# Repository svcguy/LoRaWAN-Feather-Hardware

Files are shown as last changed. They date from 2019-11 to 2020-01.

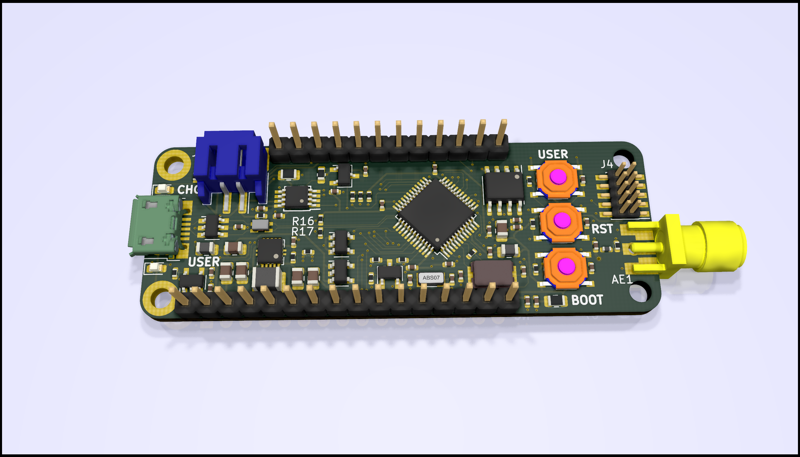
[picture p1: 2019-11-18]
doc/loRaWan1262_jlc.png

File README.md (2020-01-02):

# LoRaWAN Feather
## Overview
An Adafruit Feather compatiable board that is LoRaWAN compatible.  Designed to work with the Semtech LoRaWAN reference implementation.  Based on the STM32L073 micro and the Dorji DRF1262T radio module (which is based on the SX1262).  The board has the following hardware features:
* LiPo battery connector and charging as warranted by the Feather spec  
* LiPo fuel gauging as expected by the LoRaWAN reference implementation  
* Implements native USB  
* Connections for I2C, SPI, UART, GPIO, Analog and DAC.  
* An efficent DC-DC buck/boost switch mode converter.  
* Includes an ARM Cortex 10pin SWD debug connector  
* Antenna footprint supports edge mount SMA, u.FL and pigtail connections
* Footprint for U8 can support a hard secure element (ATECC608 or compatible) or an I2C FRAM allowing the user to experiment with hardware encryption or be LoRaWAN 1.1 compliant
* Includes one USER button as well as RESET and BOOT buttons  
* Includes one USER LED and a CHARGE LED.

## Changelog
### REV A0
Inital release
### REV B0
* Fix STC3100 grounding
* Make R16,R17 DNP by default
* Bump Bot Silk to REVB0
### REV C0
* Make U8 footprint capable of crypto and fram device
* Minor updates to schematic
* Minor updates to doc prints
* Update bot silk to REV C0

## Open Source
All schematics, pcb files, gerbers, BOM, CPL are available in this repo.  Part numbers for LCSC and Digikey are included

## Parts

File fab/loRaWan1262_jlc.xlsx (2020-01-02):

Comment | Designator | Footprint | Digikey | LCSC
Antenna_Shield | AE1 | Custom_KICAD:RF_ANT | CON-SMA-EDGE-S-ND | C129604
10uF | C10,C11,C30 | jlcpcb_smt:C_0805_2012Metric | 490-14381-1-ND | C15850
DNP | C12 | jlcpcb_smt:R_0402_1005Metric | DNP | DNP
DNP | C14 | jlcpcb_smt:C_0402_1005Metric | DNP | DNP
30pF | C24,C26 | jlcpcb_smt:C_0402_1005Metric | 311-1666-1-ND | C1570
15pF | C27,C29 | jlcpcb_smt:C_0402_1005Metric | 311-1017-1-ND | C1548
220nF | C3 | jlcpcb_smt:C_0402_1005Metric | 311-1035-1-ND | C16772
0.1uF | C4,C9,C15,C17,C18,C19,C20,C28,C25,C21,C23,C32 | jlcpcb_smt:C_0402_1005Metric | 490-14603-1-ND | C1525
1uF | C5,C6,C13,C16,C22,C1,C2,C33 | jlcpcb_smt:C_0402_1005Metric | 311-1439-1-ND | C52923
4.7uF | C7,C8,C31 | jlcpcb_smt:C_0805_2012Metric | 490-14466-1-ND | C1779
CHG | D1 | jlcpcb_smt:LED_0603_1608Metric | 160-1448-1-ND | C72038
USER | D2 | jlcpcb_smt:LED_0603_1608Metric | 160-1447-1-ND | C72043
MountingHole | H1,H2 | MountingHole:MountingHole_2.7mm_M2.5 | DNP | DNP
MountingHole_Pad | H3,H4 | MountingHole:MountingHole_2.7mm_M2.5_Pad | DNP | DNP
BAT | J1 | Connector_JST:JST_PH_S2B-PH-SM4-TB_1x02-1MP_P2.00mm_Horizontal | 455-1749-1-ND
Feather_BOT | J2 | Connector_PinHeader_2.54mm:PinHeader_1x16_P2.54mm_Vertical | DNP | DNP
Feather_TOP | J3 | Connector_PinHeader_2.54mm:PinHeader_1x12_P2.54mm_Vertical | DNP | DNP
SWD | J4 | Connector_PinHeader_1.27mm:PinHeader_2x05_P1.27mm_Vertical_SMD | SAM8796-ND | DNP
USB_B_Micro | J5 | Connector_USB:USB_Micro-B_Amphenol_10103594-0001LF_Horizontal | 609-4050-1-ND | C428495
2.2uH | L1 | jlcpcb_smt:L_1210_3225Metric | 490-2501-1-ND | C86074
FERRITE | L2 | jlcpcb_smt:R_0805_2012Metric | 587-1932-1-ND | C1015
0 | L3 | jlcpcb_smt:L_0402_1005Metric | 311-0.0JRCT-ND | C17168
FERRITE | L4,L5 | jlcpcb_smt:L_0805_2012Metric | 587-1932-1-ND | C1015
COMMON_MODE | L6 | jlcpcb_smt:COMMON_MODE_FILTER_0805 | 490-5137-1-ND | C86163
MMBT3904 | Q1 | jlcpcb_smt:TSOT-23 | MMBT3904-FDICT-ND | C20526
2k | R1 | jlcpcb_smt:R_0402_1005Metric | 311-2KLRCT-ND | C4109
330 | R10,R15,R2 | jlcpcb_smt:R_0402_1005Metric | 311-330LRCT-ND | C25104
100 | R11 | jlcpcb_smt:R_0402_1005Metric | 311-100LRTR-ND | C25076
0 | R12 | jlcpcb_smt:R_0402_1005Metric | 311-0.0JRCT-ND | C17168
1.5k | R16,R17 | jlcpcb_smt:R_0402_1005Metric | DNP | DNP
4.7k | R18,R19 | jlcpcb_smt:R_0402_1005Metric | 311-4.7KJRCT-ND | C25900
0.03 | R3 | jlcpcb_smt:R_0805_2012Metric | P124412CT-ND | C247605
200k | R5 | jlcpcb_smt:R_0603_1608Metric | A119933CT-ND | C61953
1k | R7,R4 | jlcpcb_smt:R_0402_1005Metric | 311-1.00KLRCT-ND | C11702
10k | R9,R8,R13,R14,R6 | jlcpcb_smt:R_0402_1005Metric | 311-10.0KLRTR-ND | C25744
USER | SW1 | jlcpcb_smt:TS_1187A | EG2531CT-ND | C318884
RESET | SW2 | jlcpcb_smt:TS_1187A | EG2531CT-ND | C318884
BOOT | SW3 | jlcpcb_smt:TS_1187A | EG2531CT-ND | C318884
MCP73831-2-OT | U1 | jlcpcb_smt:TSOT-23-5 | MCP73831T-2ATI/OTCT-ND | C424093
USBLC6-2SC6 | U10 | jlcpcb_smt:TSOT-23-6 | 497-5235-1-ND | C7519
STC3100 | U2 | jlcpcb_smt:MSOP-8_3x3mm_P0.65mm | 497-10526-1-ND
XC6206 | U3 | jlcpcb_smt:TSOT-23 | MCP1700T3302ETTCT-ND | C5446
MAX40200AUK | U5,U4 | Package_TO_SOT_SMD:SOT-23-5 | MAX40200AUK+TCT-ND
TPS63001 | U6 | jlcpcb_smt:Texas_S-PVSON-N10_ThermalVias | 296-19643-1-ND | C28060
DRF1262x | U7 | Custom_KICAD:DRF1262x | DNP | DNP
ATECC608A-SSHDA | U8 | jlcpcb_smt:SOIC-8_3.9x4.9mm_P1.27mm | ATECC608A-SSHCZ-TCT-ND | C376619
FM24CL04B | U8 | jlcpcb_smt:SOIC-8_3.9x4.9mm_P1.27mm | 428-3741-1-ND | C66016
STM32L073CZTx | U9 | jlcpcb_smt:LQFP-48_7x7mm_P0.5mm | 497-17506-ND | DNP
8MHz | Y1 | jlcpcb_smt:Crystal_SMD_Abracon_ABM3-2Pin_5.0x3.2mm | 535-10630-1-ND | C115962
32.768kHz | Y2 | jlcpcb_smt:Crystal_SMD_3215-2Pin_3.2x1.5mm | 535-9542-1-ND | C32346

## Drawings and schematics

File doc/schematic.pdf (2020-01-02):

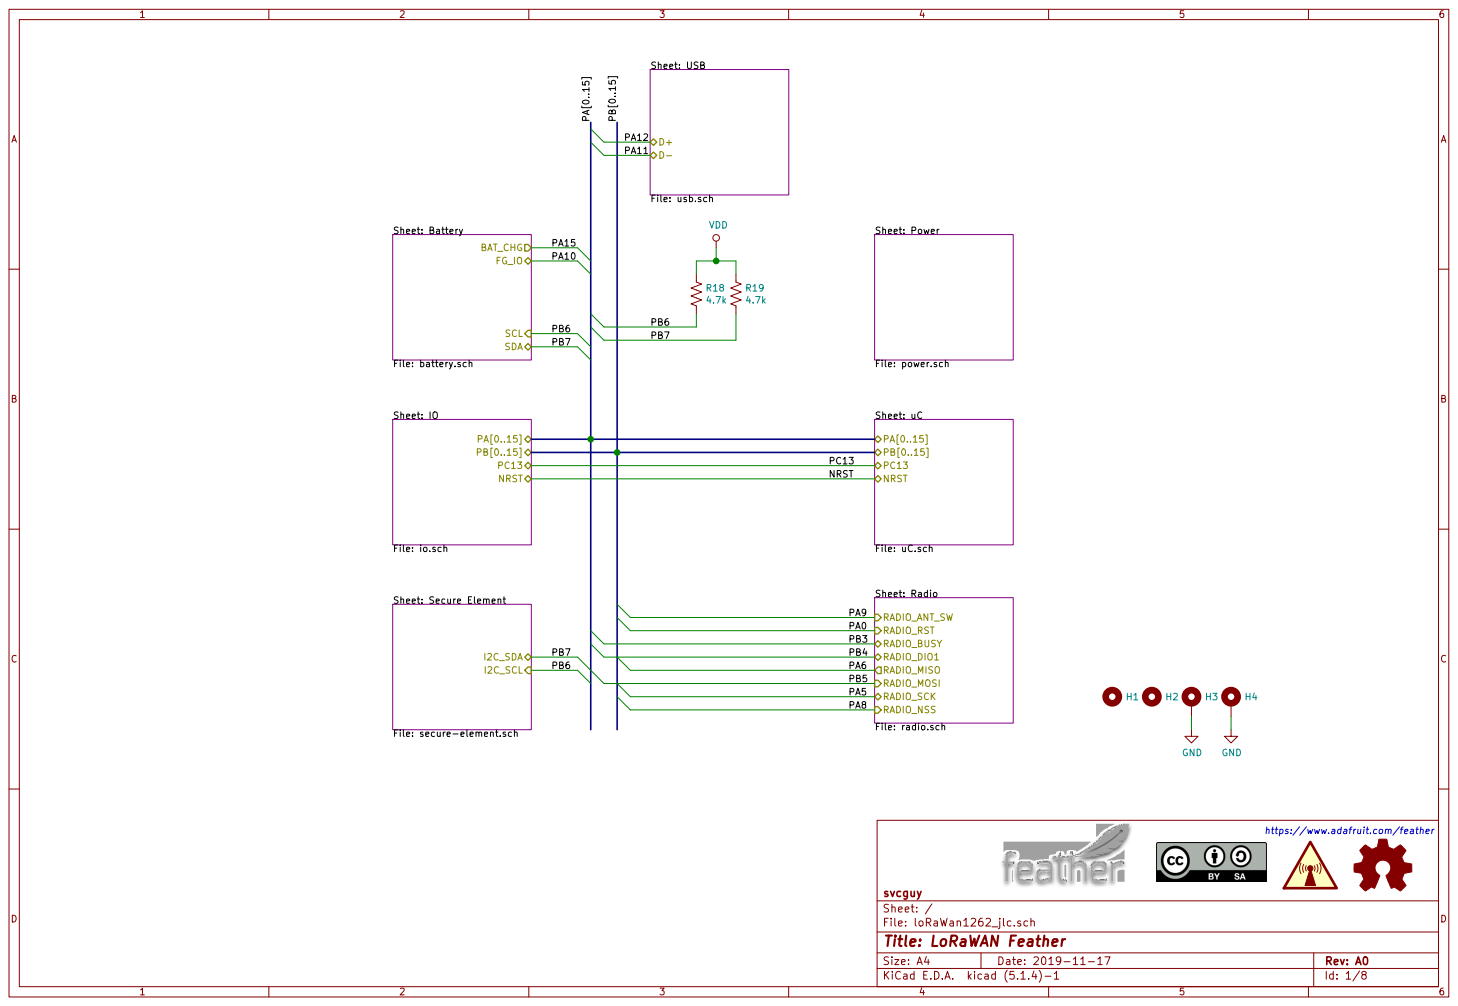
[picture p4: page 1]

PB[0..15] NRST Sheet: USB

File: usb.sch D+D- Sheet: IO

PB[0..15] NRST PC13 Sheet: Battery

4.7k VDD
Sheet: Power File: power.sch Sheet: Radio File: radio.sch RADIO_ANT_SW

File: uC.sch PC13 PA[0..15]

RADIO_RST RADIO_BUSY RADIO_DIO1 Sheet: Secure Element File: secure-element.sch

https://www.adafruit.com/feather

File: loRaWan1262_jlc.sch Sheet: / svcguy

Id: 1/8 Title: LoRaWAN Feather

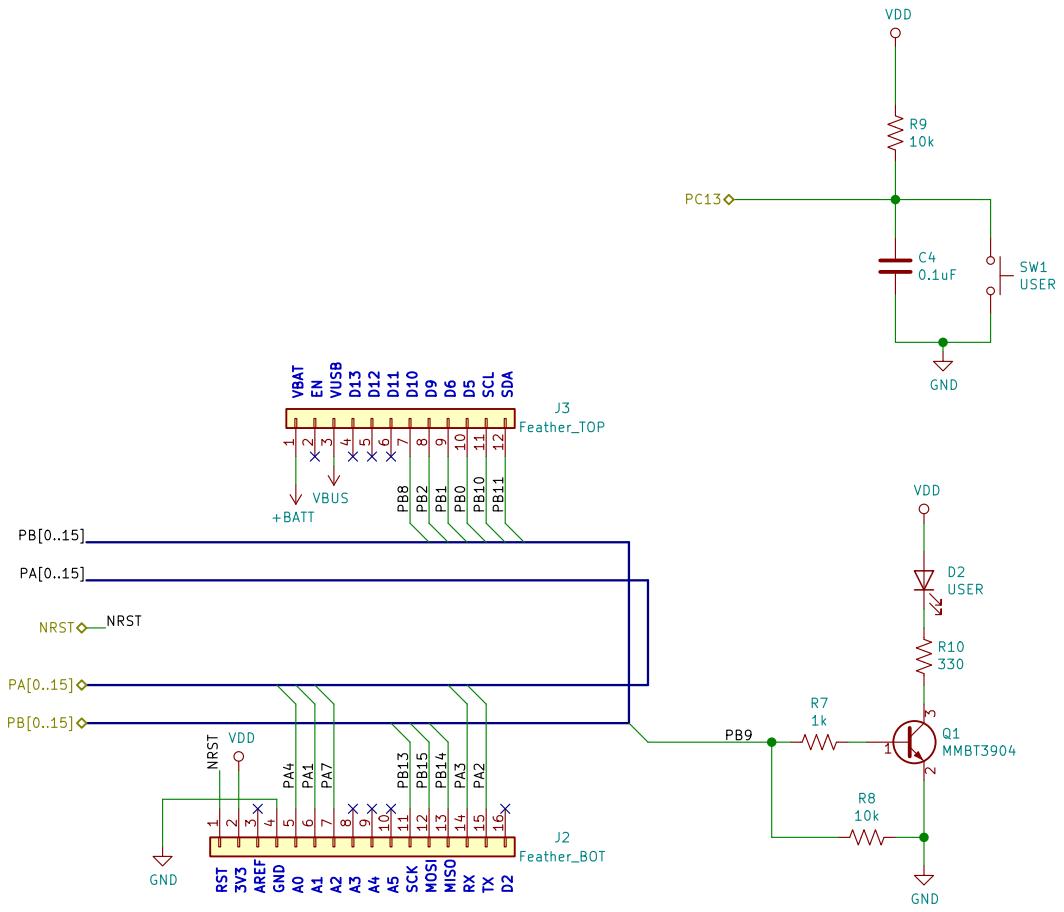
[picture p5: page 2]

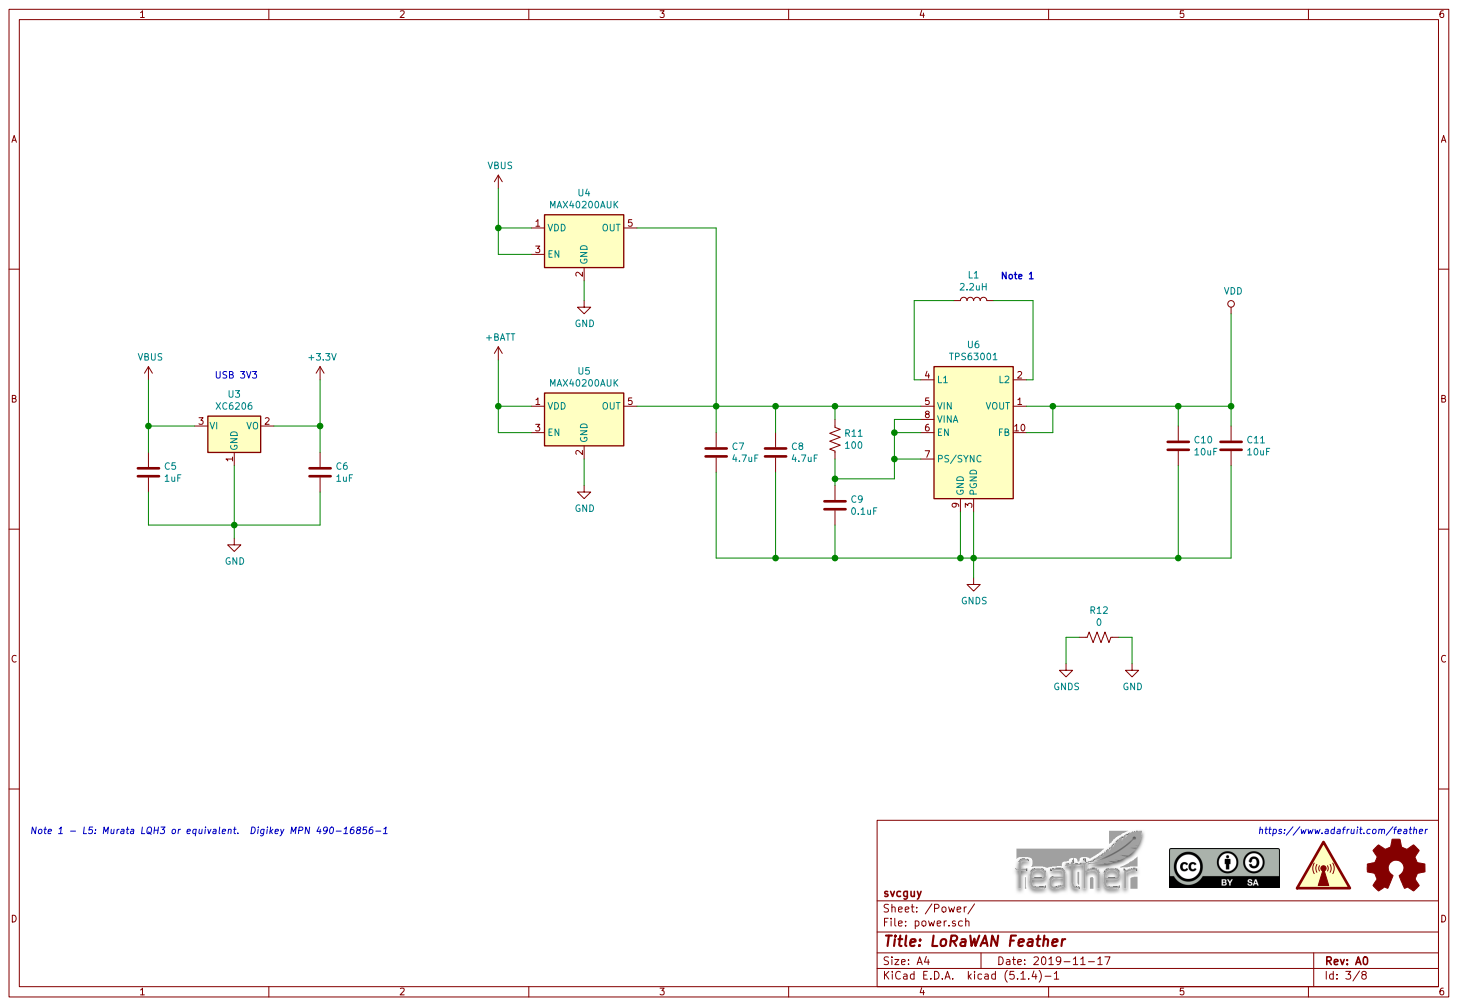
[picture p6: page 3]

2 EN 3 OUT 5 U4 MAX40200AUK GND GND GNDS GNDS GND

Id: 3/8 Title: LoRaWAN Feather

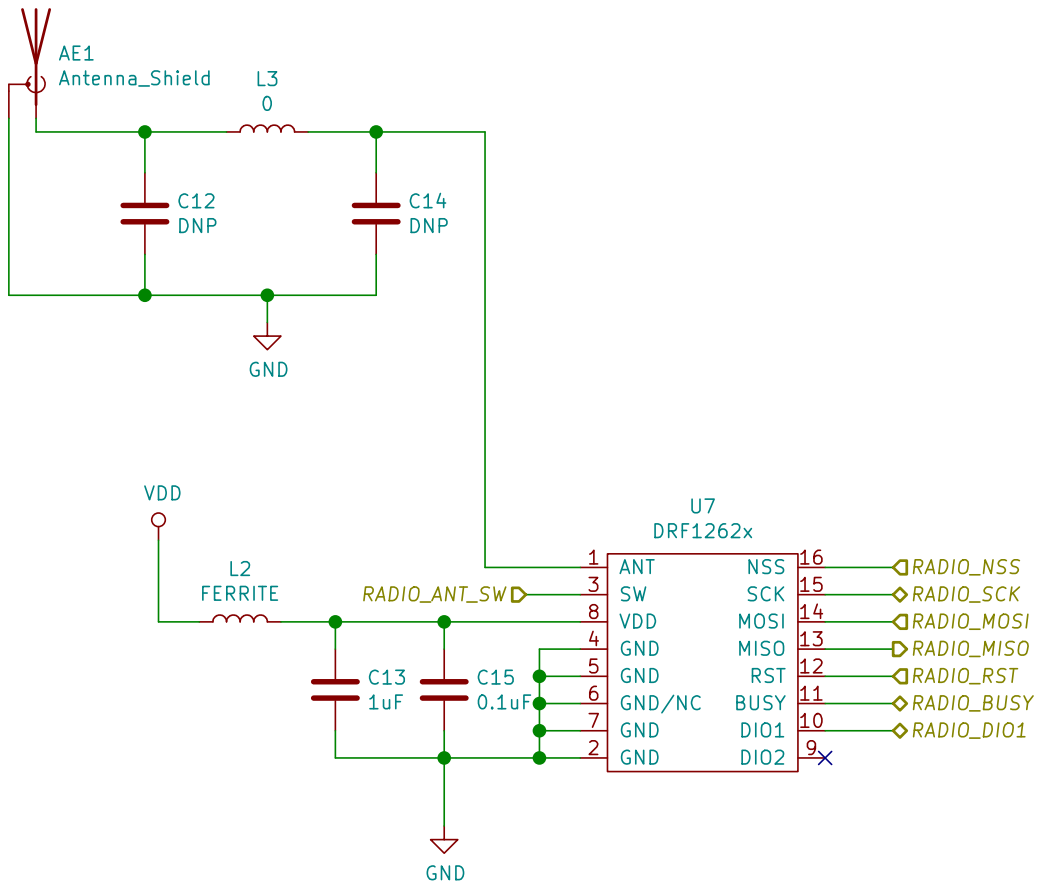
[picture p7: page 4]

https://www.adafruit.com/feather

Id: 4/8 Title: LoRaWAN Feather File: radio.sch Sheet: /Radio/ svcguy

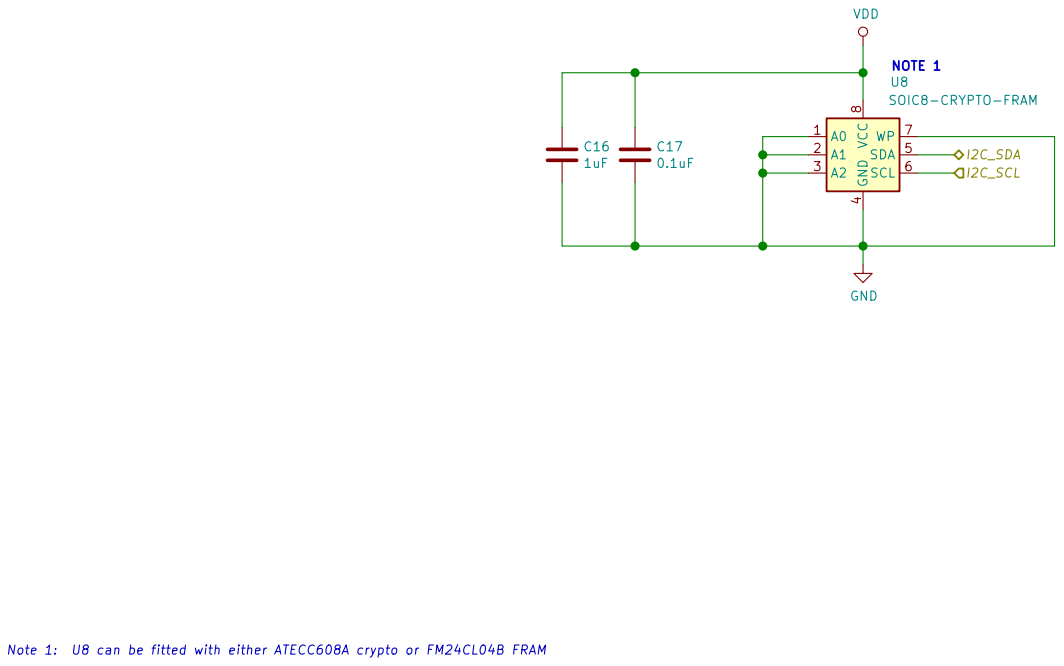
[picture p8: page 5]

https://www.adafruit.com/feather NOTE 1 Note 1: U8 can be fitted with either ATECC608A crypto or FM24CL04B FRAM

4 SDA 5 SCL 6 WP 7 VCC

Id: 5/8 Title: LoRaWAN Feather File: secure-element.sch Sheet: /Secure Element/ svcguy C16

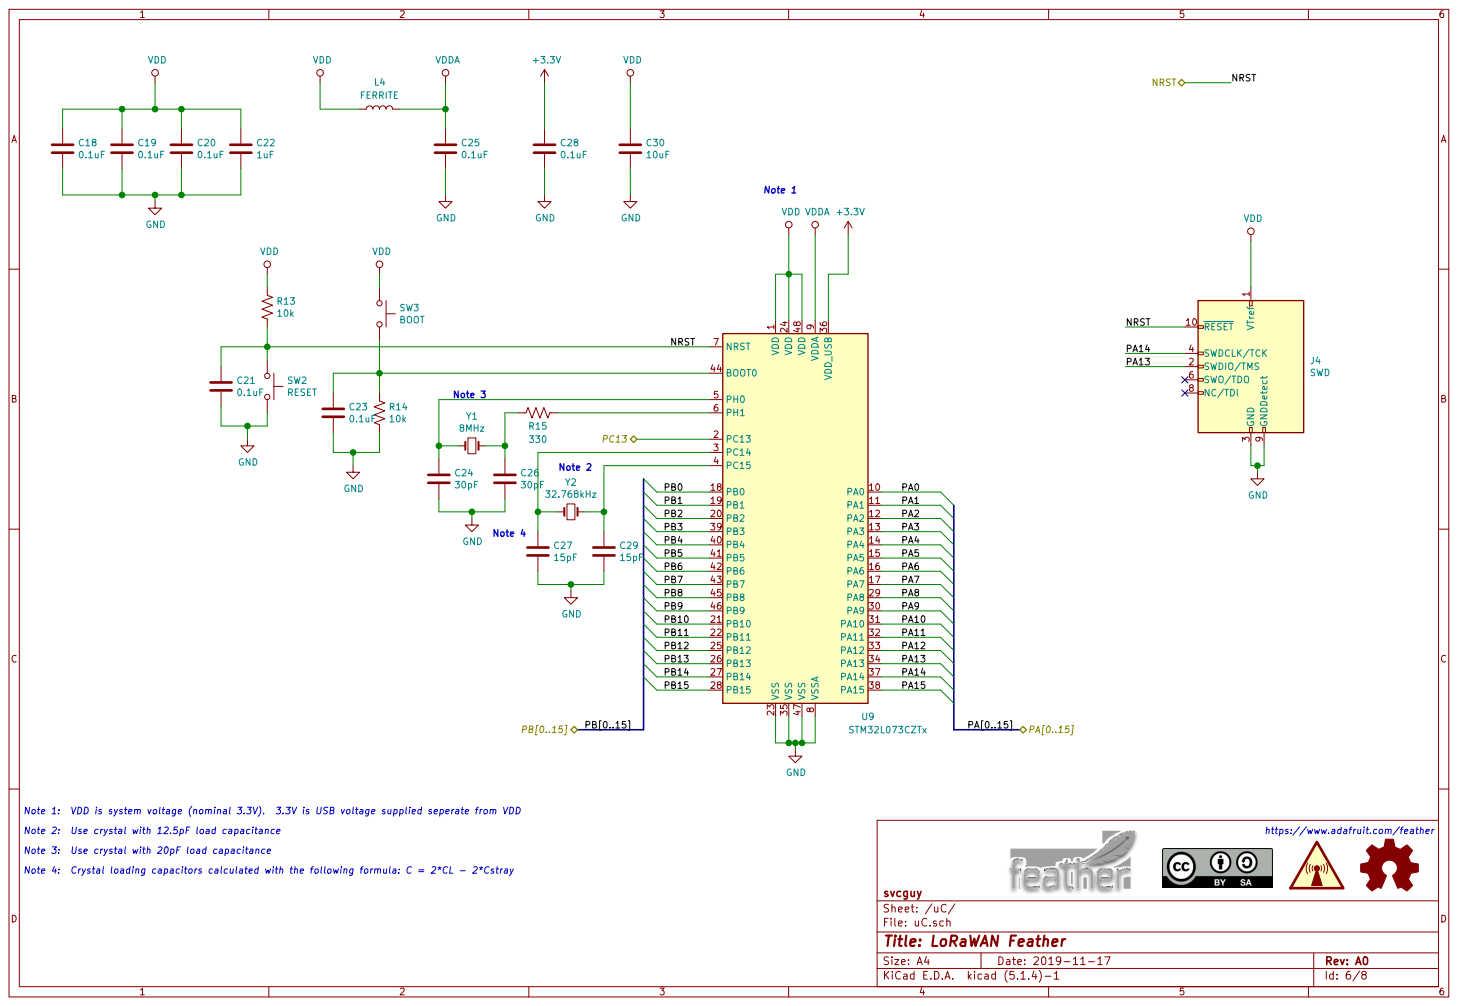
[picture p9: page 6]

9 VDD_USB 36 VSS 23 VSS 35 VSS 47 VSSA

3 SWDCLK/TCK 4 SWO/TDO 6 NC/TDI 8 GNDDetect 9

Note 1: VDD is system voltage (nominal 3.3V). 3.3V is USB voltage supplied seperate from VDD

https://www.adafruit.com/feather

Note 4: Crystal loading capacitors calculated with the following formula: C = 2*CL - 2*Cstray

Id: 6/8 Title: LoRaWAN Feather File: uC.sch Sheet: /uC/ svcguy

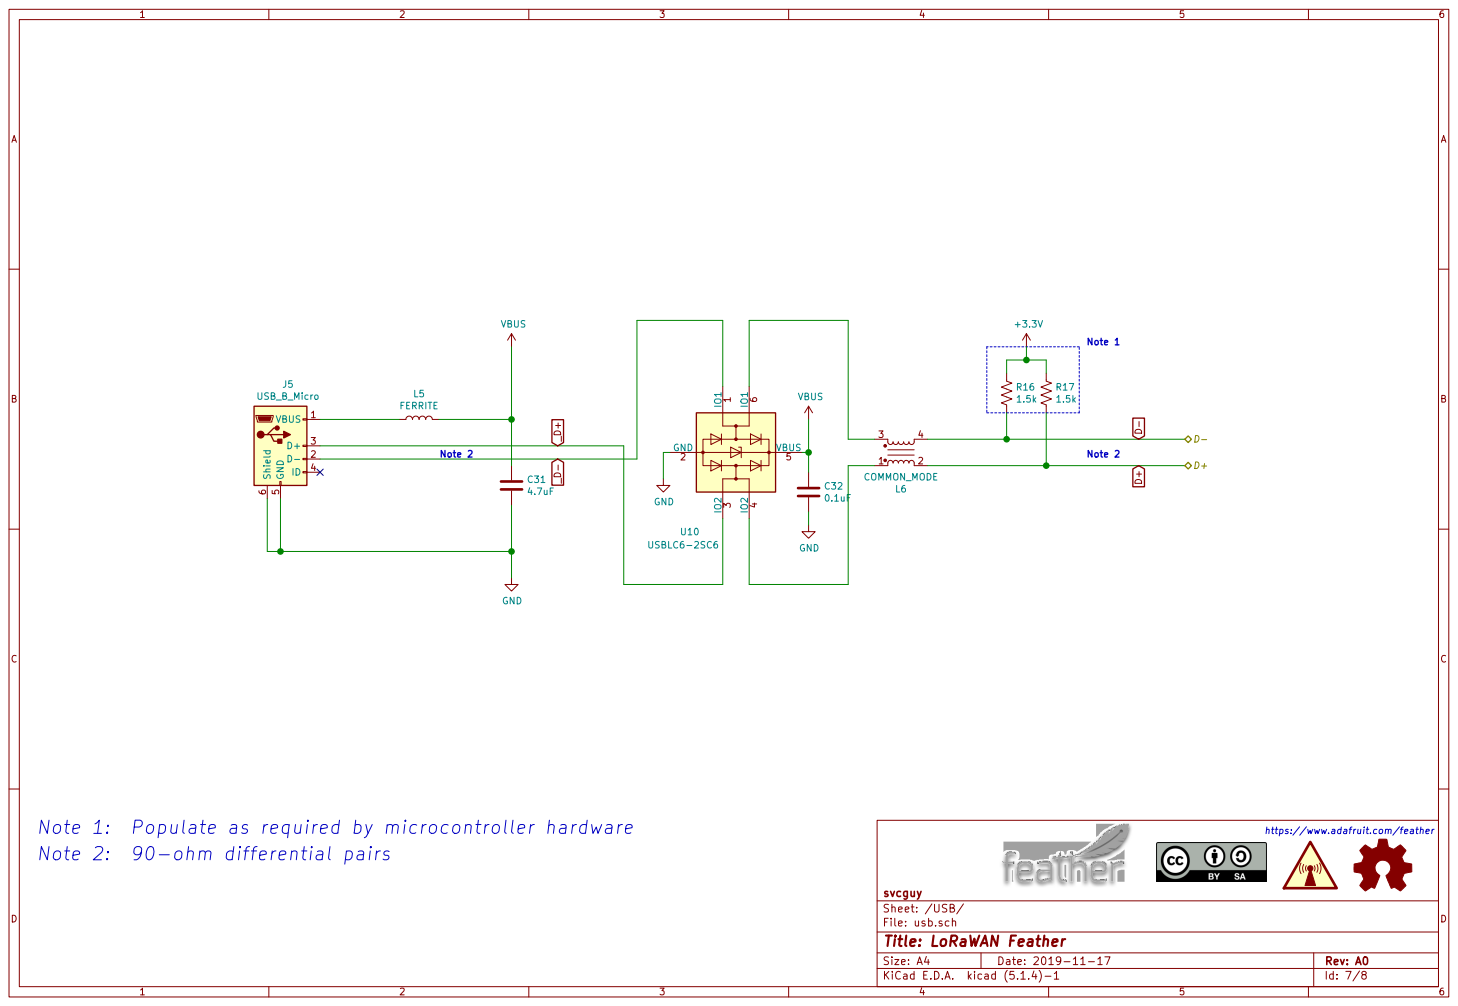
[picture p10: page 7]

https://www.adafruit.com/feather

Note 2: 90-ohm differential pairs

Id: 7/8 Title: LoRaWAN Feather File: usb.sch Sheet: /USB/ svcguy

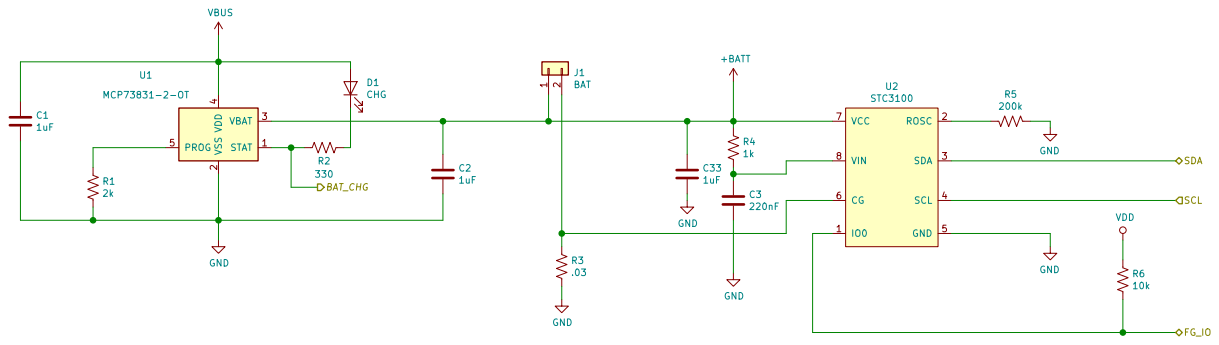
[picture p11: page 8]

4 PROG 5 U1 MCP73831-2-OT VBUS D1 CHG

https://www.adafruit.com/feather

Sheet: /Battery/
File: battery.sch
Id: 8/8 Title: LoRaWAN Feather

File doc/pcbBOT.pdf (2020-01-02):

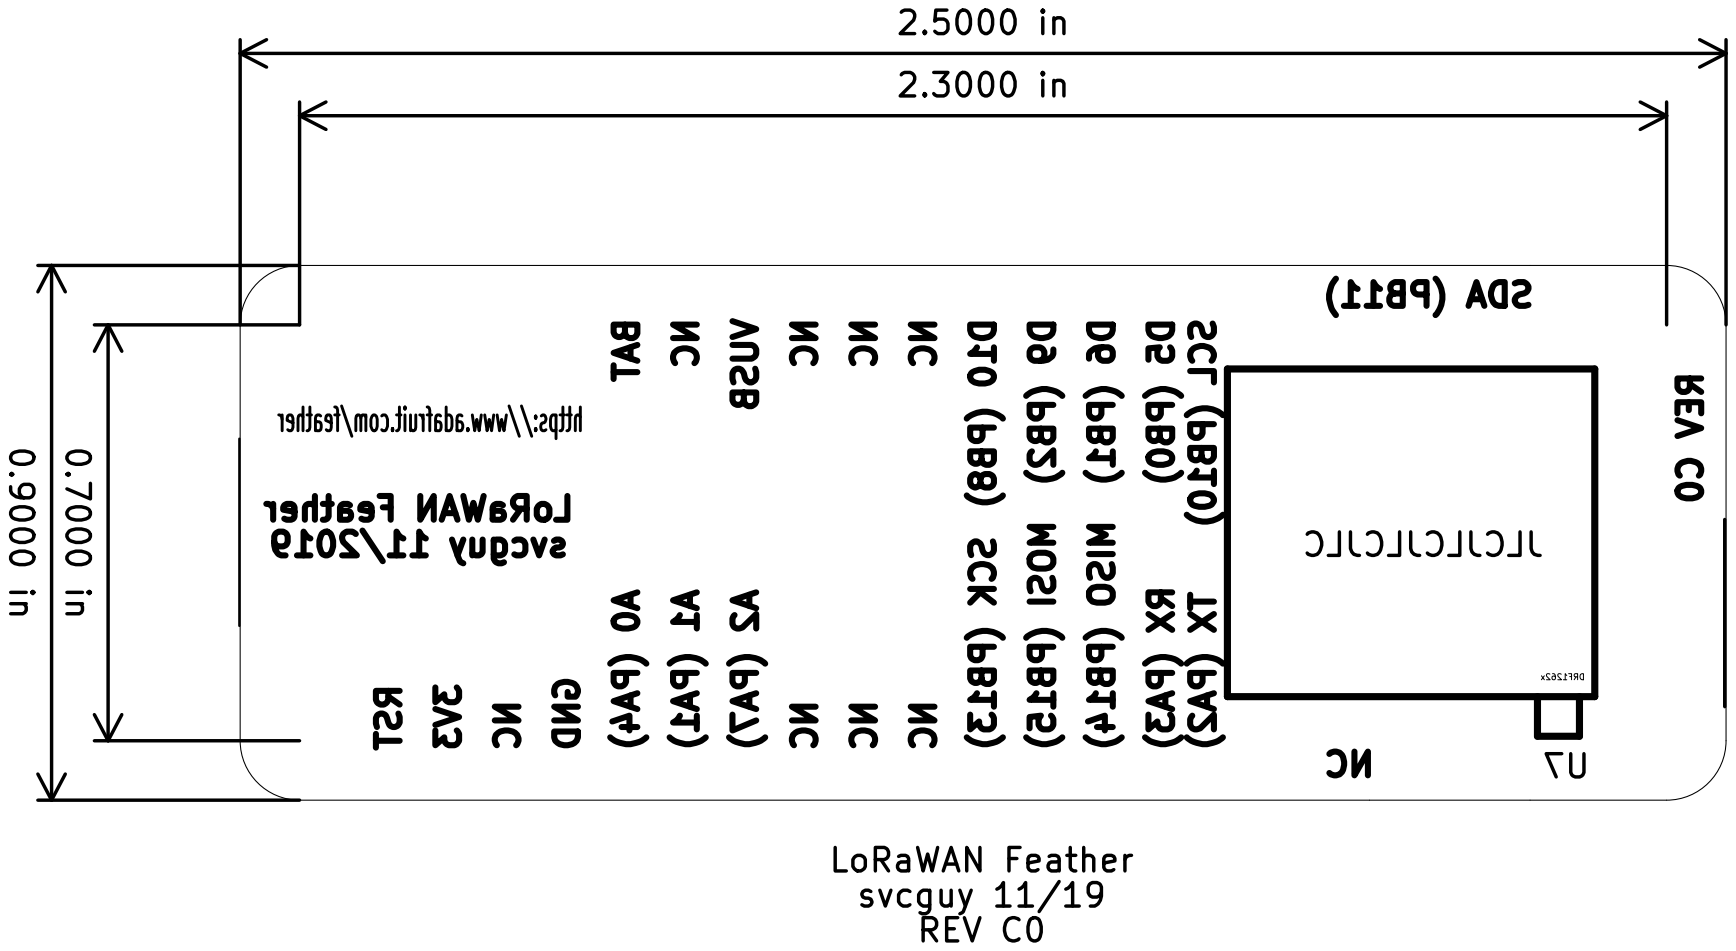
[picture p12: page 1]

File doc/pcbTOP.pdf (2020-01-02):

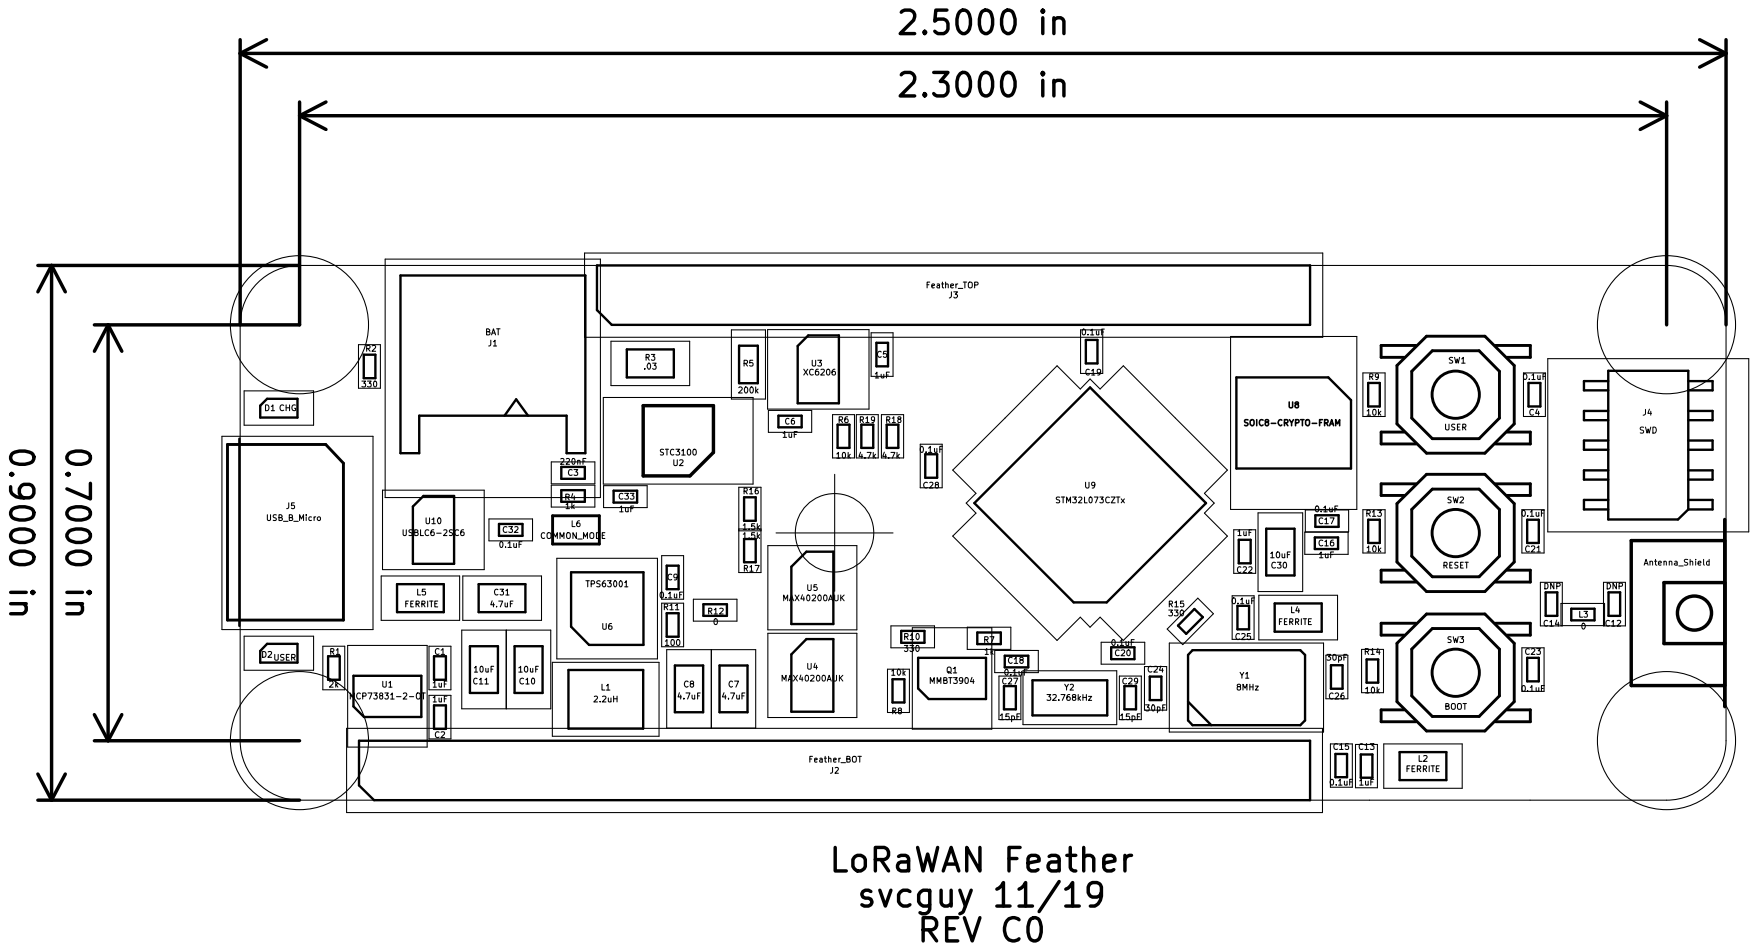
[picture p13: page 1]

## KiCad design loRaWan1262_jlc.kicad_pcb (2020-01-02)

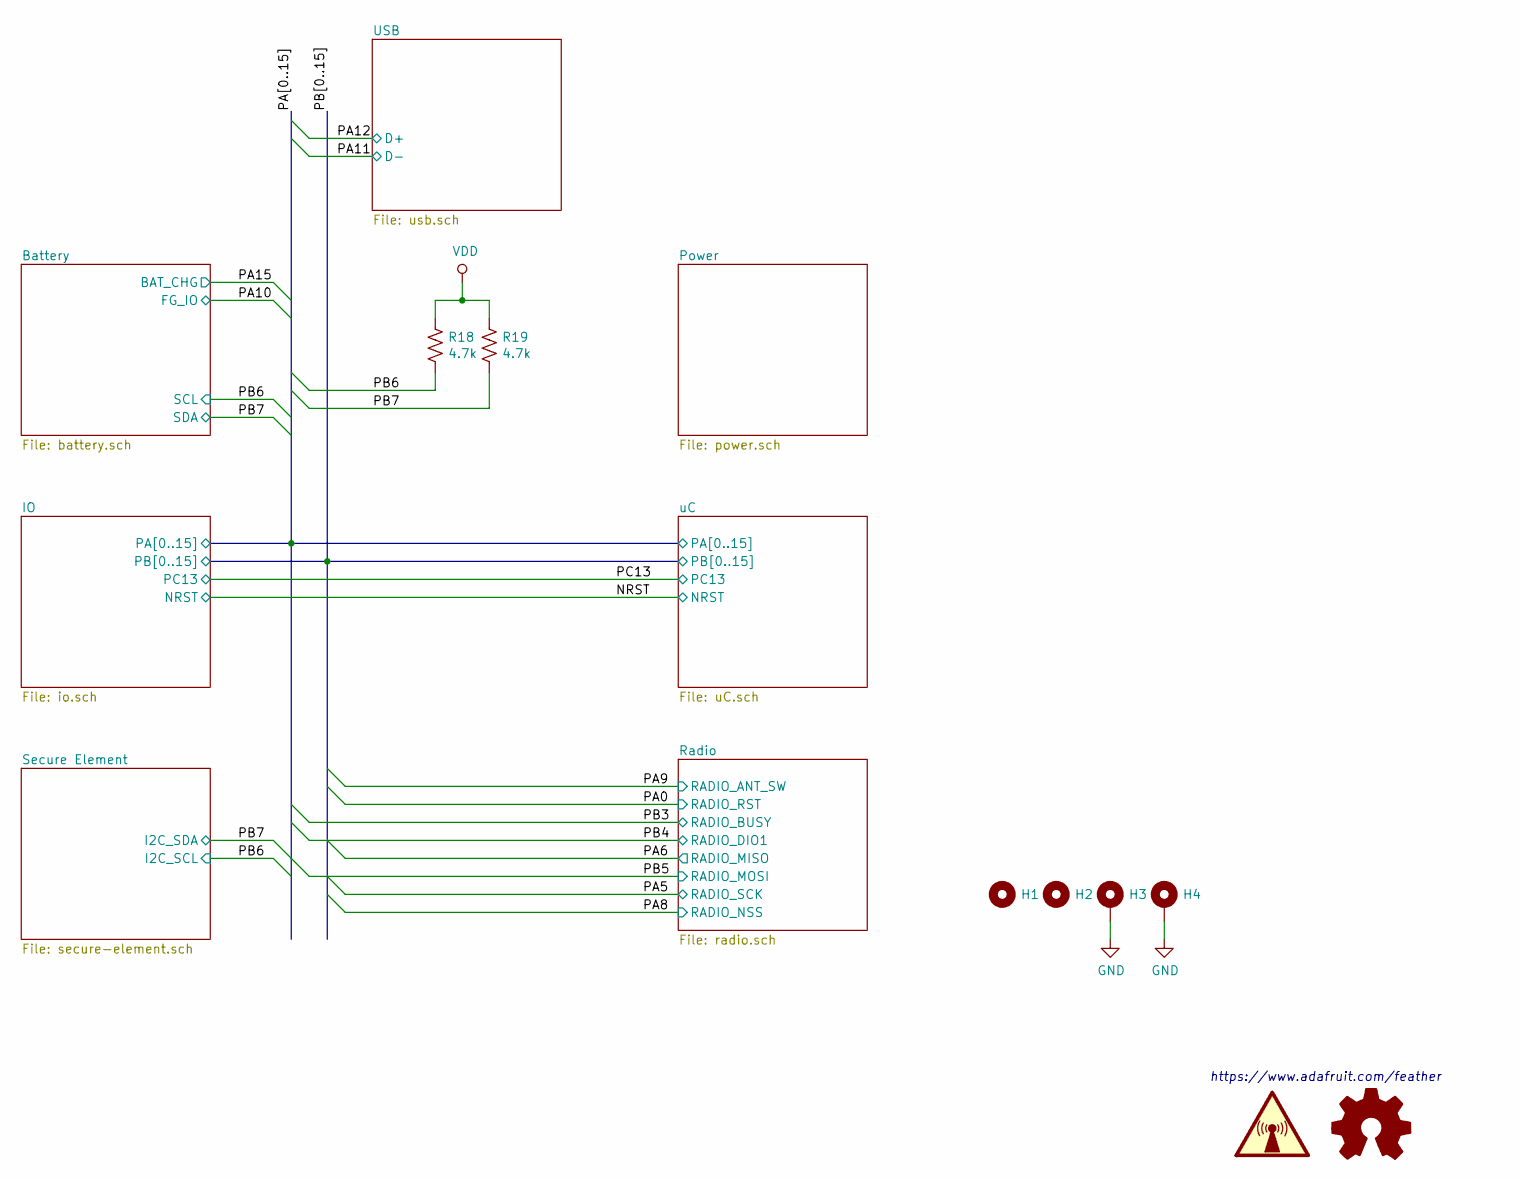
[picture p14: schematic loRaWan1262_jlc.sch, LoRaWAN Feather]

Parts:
H1, H2: MountingHole; MountingHole_2.7mm_M2.5; LCSC DNP
H3, H4: MountingHole_Pad; MountingHole_2.7mm_M2.5_Pad; LCSC DNP
R18, R19: 4.7k; R_0402_1005Metric; LCSC C25900

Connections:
/PB6: R18.2; also elsewhere on the board
/PB7: R19.2; also elsewhere on the board
GND: H3.1, H4.1; also elsewhere on the board
VDD: R18.1, R19.1; also elsewhere on the board

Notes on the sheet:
https://www.adafruit.com/feather

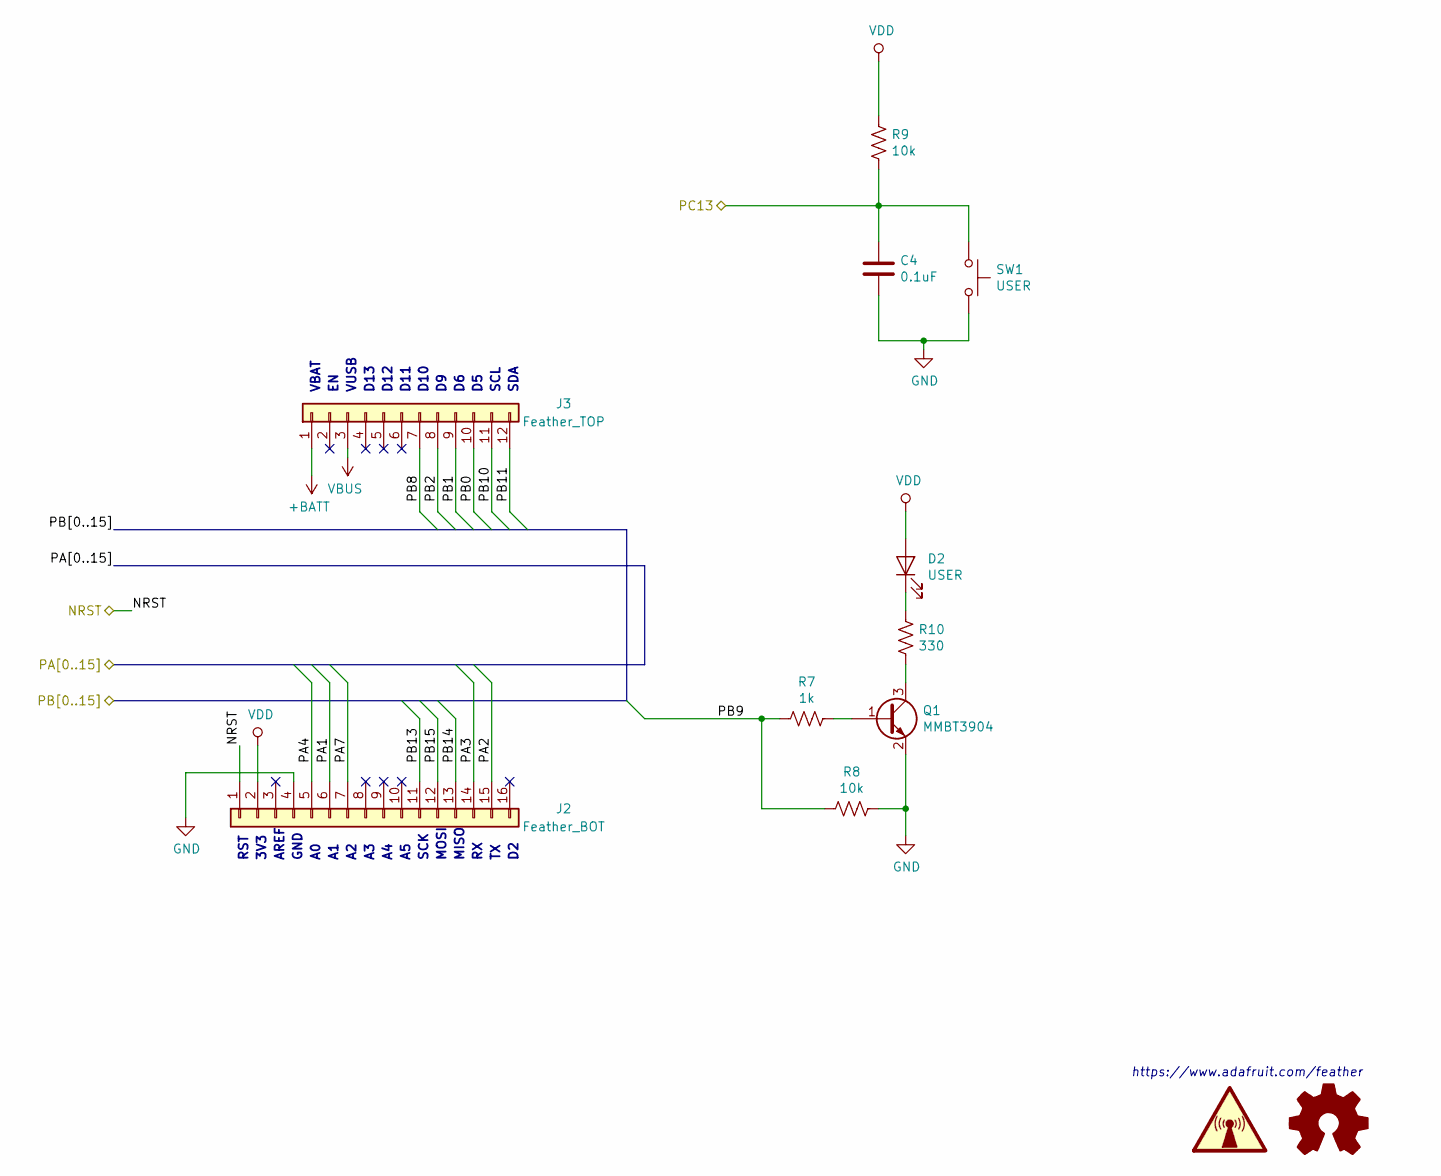
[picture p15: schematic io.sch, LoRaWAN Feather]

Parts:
C4: 0.1uF; C_0402_1005Metric; LCSC C1525
D2: USER; LED_0603_1608Metric; LCSC C72043
J2: Feather_BOT; PinHeader_1x16_P2.54mm_Vertical; LCSC DNP
J3: Feather_TOP; PinHeader_1x12_P2.54mm_Vertical; LCSC DNP
Q1: MMBT3904; TSOT-23; LCSC C20526
R7: 1k; R_0402_1005Metric; LCSC C11702
R8, R9: 10k; R_0402_1005Metric; LCSC C25744
R10: 330; R_0402_1005Metric; LCSC C25104
SW1: USER; TS_1187A; LCSC C318884

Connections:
+BATT: J3.1; also elsewhere on the board
/IO/PA1: J2.6; also elsewhere on the board
/IO/PA2: J2.15; also elsewhere on the board
/IO/PA3: J2.14; also elsewhere on the board
/IO/PA4: J2.5; also elsewhere on the board
/IO/PA7: J2.7; also elsewhere on the board
/IO/PB0: J3.10; also elsewhere on the board
/IO/PB1: J3.9; also elsewhere on the board
/IO/PB2: J3.8; also elsewhere on the board
/IO/PB8: J3.7; also elsewhere on the board
/IO/PB9: R7.2, R8.2; also elsewhere on the board
/IO/PB10: J3.11; also elsewhere on the board
/IO/PB11: J3.12; also elsewhere on the board
/IO/PB13: J2.11; also elsewhere on the board
/IO/PB14: J2.13; also elsewhere on the board
/IO/PB15: J2.12; also elsewhere on the board
/NRST: J2.1; also elsewhere on the board
/PC13: C4.1, R9.2, SW1.1; also elsewhere on the board
GND: C4.2, J2.4, Q1.2 (E), R8.1, SW1.2; also elsewhere on the board
unnamed: D2.1 (K), R10.2
unnamed: Q1.1 (B), R7.1
unnamed: Q1.3 (C), R10.1
VBUS: J3.3; also elsewhere on the board
VDD: D2.2 (A), J2.2, R9.1; also elsewhere on the board

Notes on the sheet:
RST
3V3
AREF
GND
SCK
MOSI
MISO
VBAT
VUSB
D13
D12
D11
D10
SCL
SDA
https://www.adafruit.com/feather

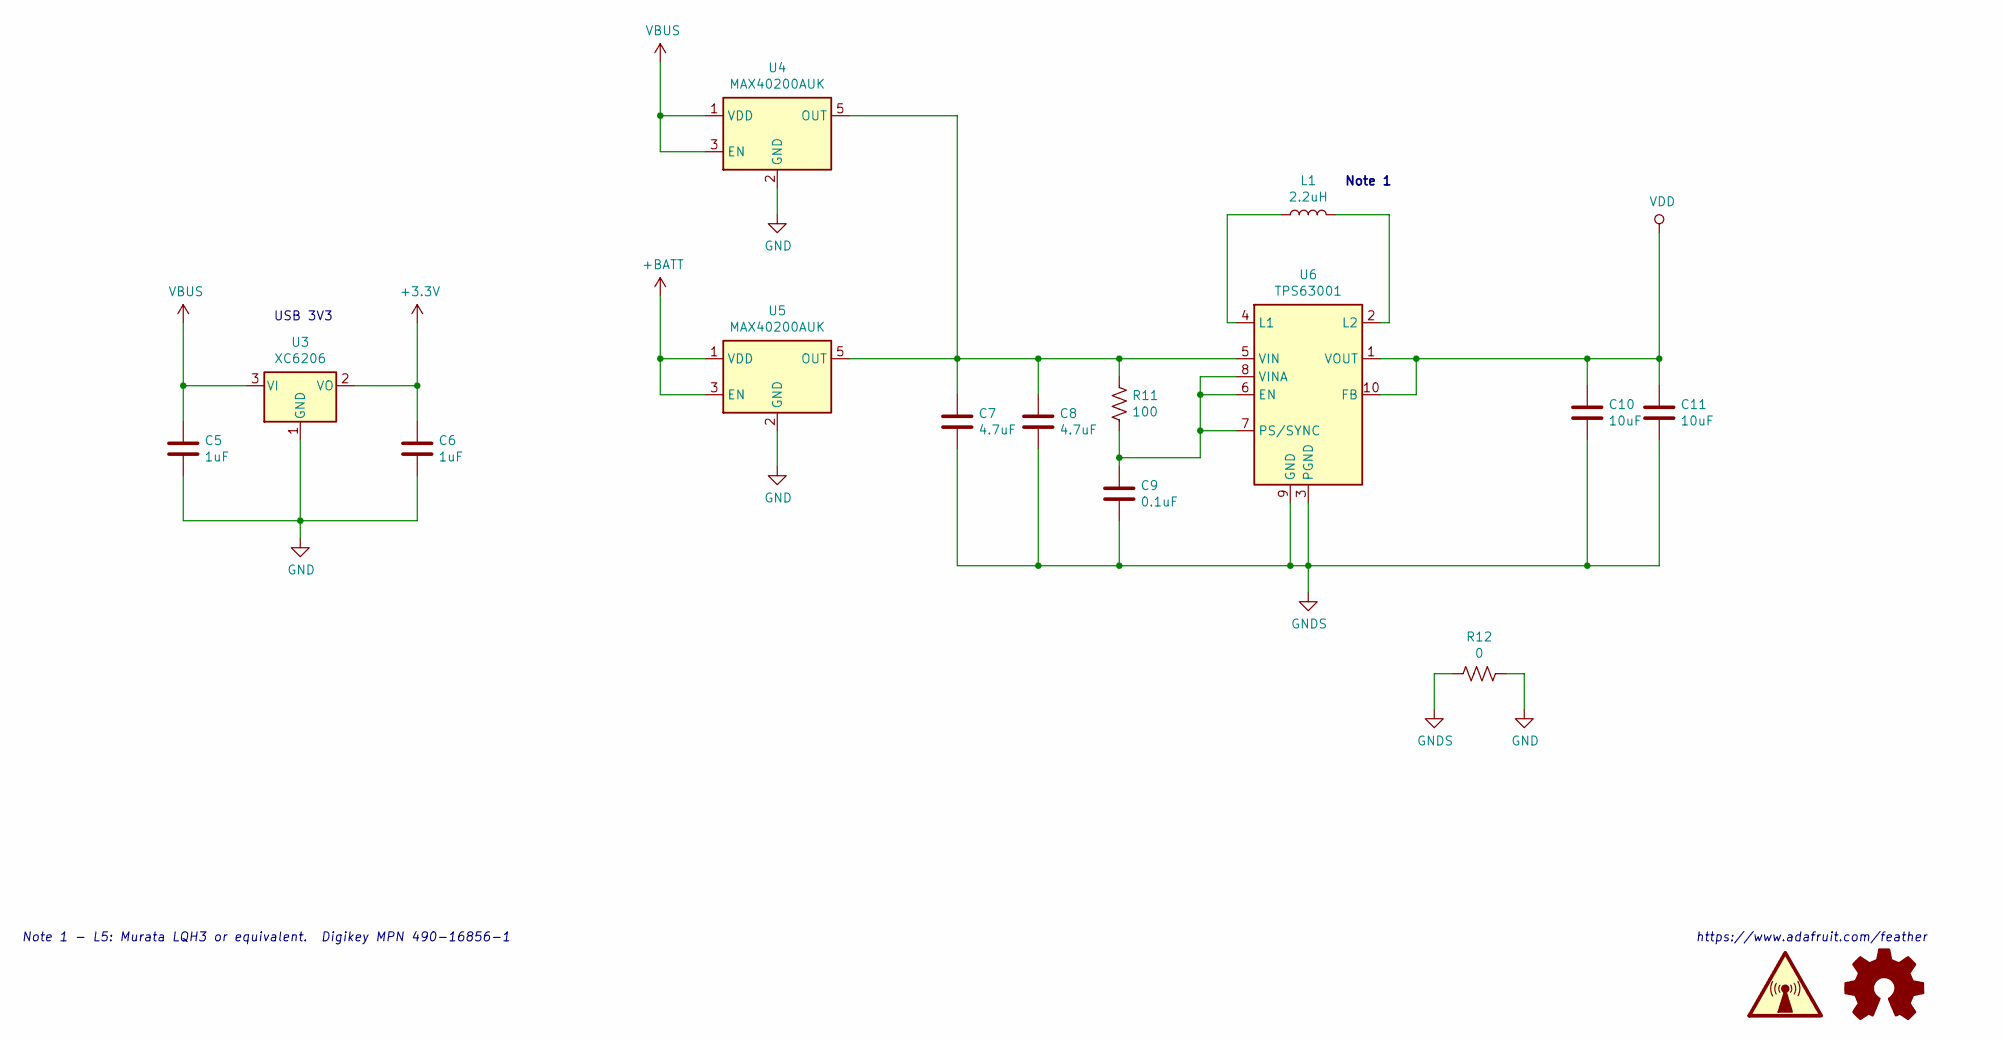
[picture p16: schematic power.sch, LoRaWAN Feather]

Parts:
C5, C6: 1uF; C_0402_1005Metric; LCSC C52923
C7, C8: 4.7uF; C_0805_2012Metric; LCSC C1779
C9: 0.1uF; C_0402_1005Metric; LCSC C1525
C10, C11: 10uF; C_0805_2012Metric; LCSC C15850
L1: 2.2uH; L_1210_3225Metric; LCSC C86074
R11: 100; R_0402_1005Metric; LCSC C25076
R12: 0; R_0402_1005Metric; LCSC C17168
U3: XC6206; TSOT-23; LCSC C5446
U4, U5: MAX40200AUK; SOT-23-5; Digikey MAX40200AUK+TCT-ND
U6: TPS63001; Texas_S-PVSON-N10_ThermalVias; LCSC C28060

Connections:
+3V3: C6.1, U3.2 (VO); also elsewhere on the board
+BATT: U5.1 (VDD), U5.3 (EN); also elsewhere on the board
GND: C5.2, C6.2, R12.1, U3.1 (GND), U4.2 (GND), U5.2 (GND); also elsewhere on the board
GNDS: C7.2, C8.2, C9.2, C10.2, C11.2, R12.2, U6.3 (PGND), U6.9 (GND), U6.11 (PGND)
unnamed: C7.1, C8.1, R11.1, U4.5 (OUT), U5.5 (OUT), U6.5 (VIN)
unnamed: C9.1, R11.2, U6.6 (EN), U6.7 (PS/SYNC), U6.8 (VINA)
unnamed: L1.1, U6.4 (L1)
unnamed: L1.2, U6.2 (L2)
VBUS: C5.1, U3.3 (VI), U4.1 (VDD), U4.3 (EN); also elsewhere on the board
VDD: C10.1, C11.1, U6.1 (VOUT), U6.10 (FB); also elsewhere on the board

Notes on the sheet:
Note 1
Note 1 - L5: Murata LQH3 or equivalent. Digikey MPN 490-16856-1
USB 3V3
https://www.adafruit.com/feather

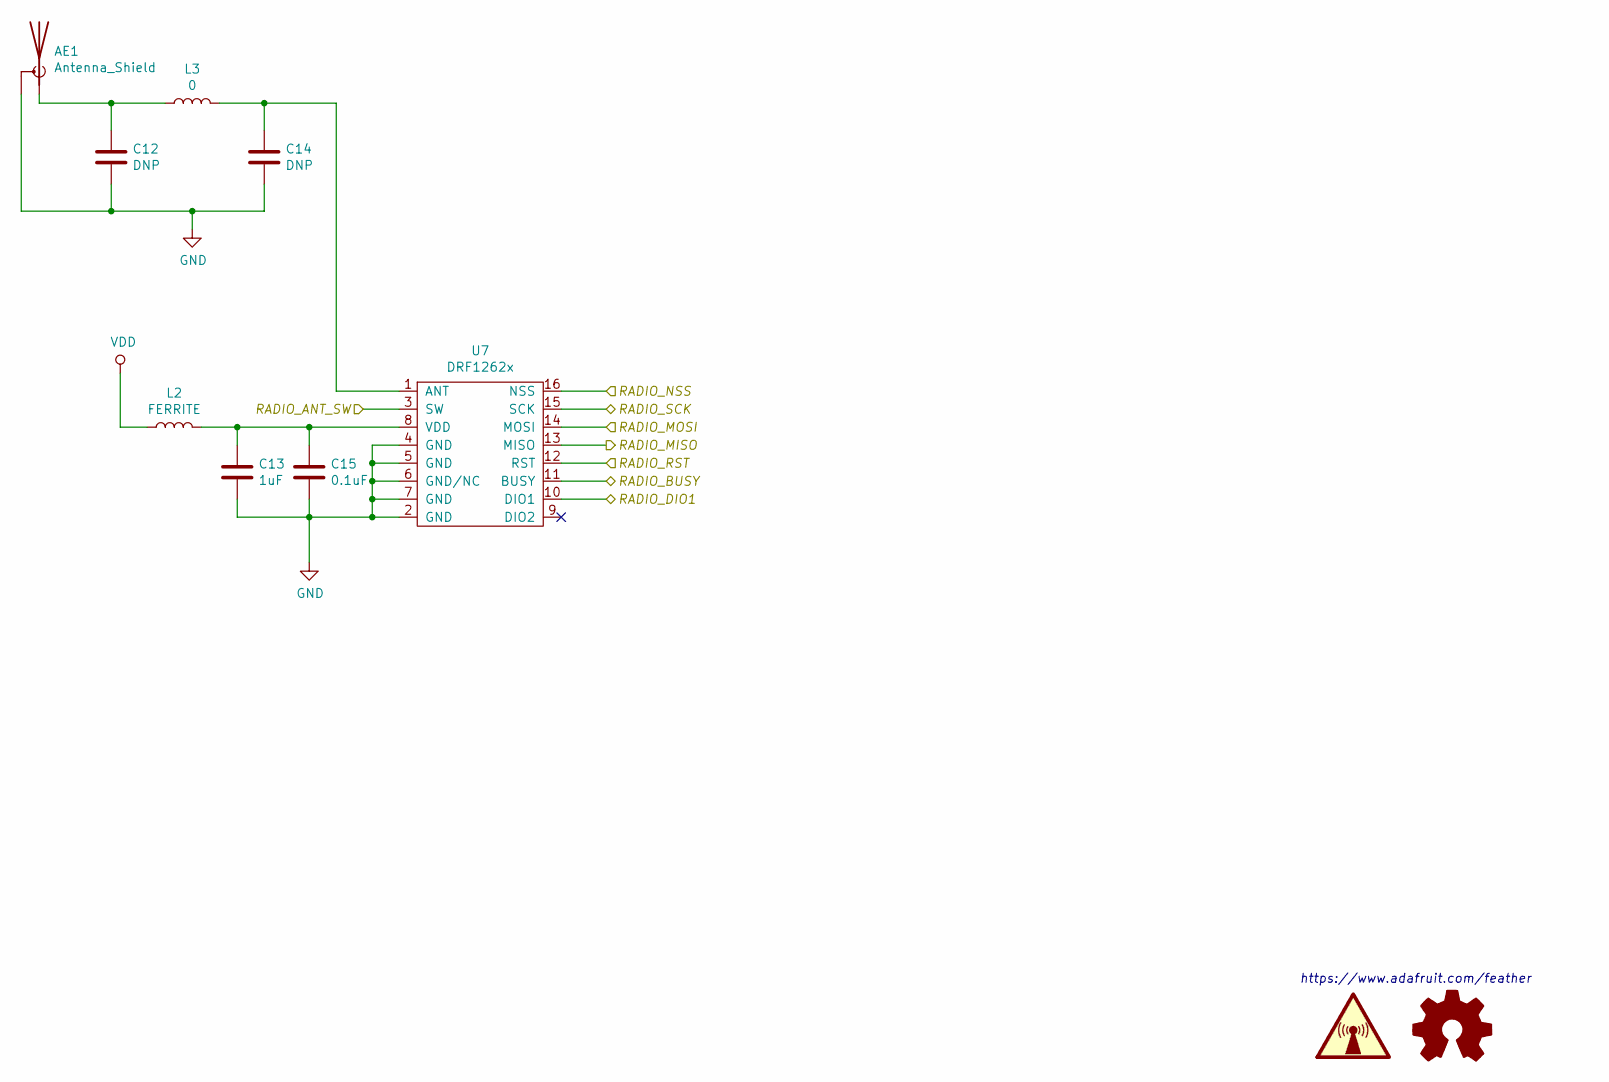
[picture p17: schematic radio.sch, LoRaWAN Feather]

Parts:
AE1: Antenna_Shield; RF_ANT; LCSC C129604
C12: DNP; R_0402_1005Metric; LCSC DNP
C13: 1uF; C_0402_1005Metric; LCSC C52923
C14: DNP; C_0402_1005Metric; LCSC DNP
C15: 0.1uF; C_0402_1005Metric; LCSC C1525
L2: FERRITE; R_0805_2012Metric; LCSC C1015
L3: 0; L_0402_1005Metric; LCSC C17168
U7: DRF1262x; LCSC DNP

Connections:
/PA0: U7.12 (RST); also elsewhere on the board
/PA5: U7.15 (SCK); also elsewhere on the board
/PA6: U7.13 (MISO); also elsewhere on the board
/PA8: U7.16 (NSS); also elsewhere on the board
/PA9: U7.3 (SW); also elsewhere on the board
/PB3: U7.11 (BUSY); also elsewhere on the board
/PB4: U7.10 (DIO1); also elsewhere on the board
/PB5: U7.14 (MOSI); also elsewhere on the board
GND: AE1.2 (Shield), C12.2, C13.2, C14.2, C15.2, U7.2 (GND), U7.4 (GND), U7.5 (GND), U7.6 (GND/NC), U7.7 (GND); also elsewhere on the board
unnamed: AE1.1 (A), C12.1, L3.1
unnamed: C13.1, C15.1, L2.2, U7.8 (VDD)
unnamed: C14.1, L3.2, U7.1 (ANT)
VDD: L2.1; also elsewhere on the board

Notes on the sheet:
https://www.adafruit.com/feather

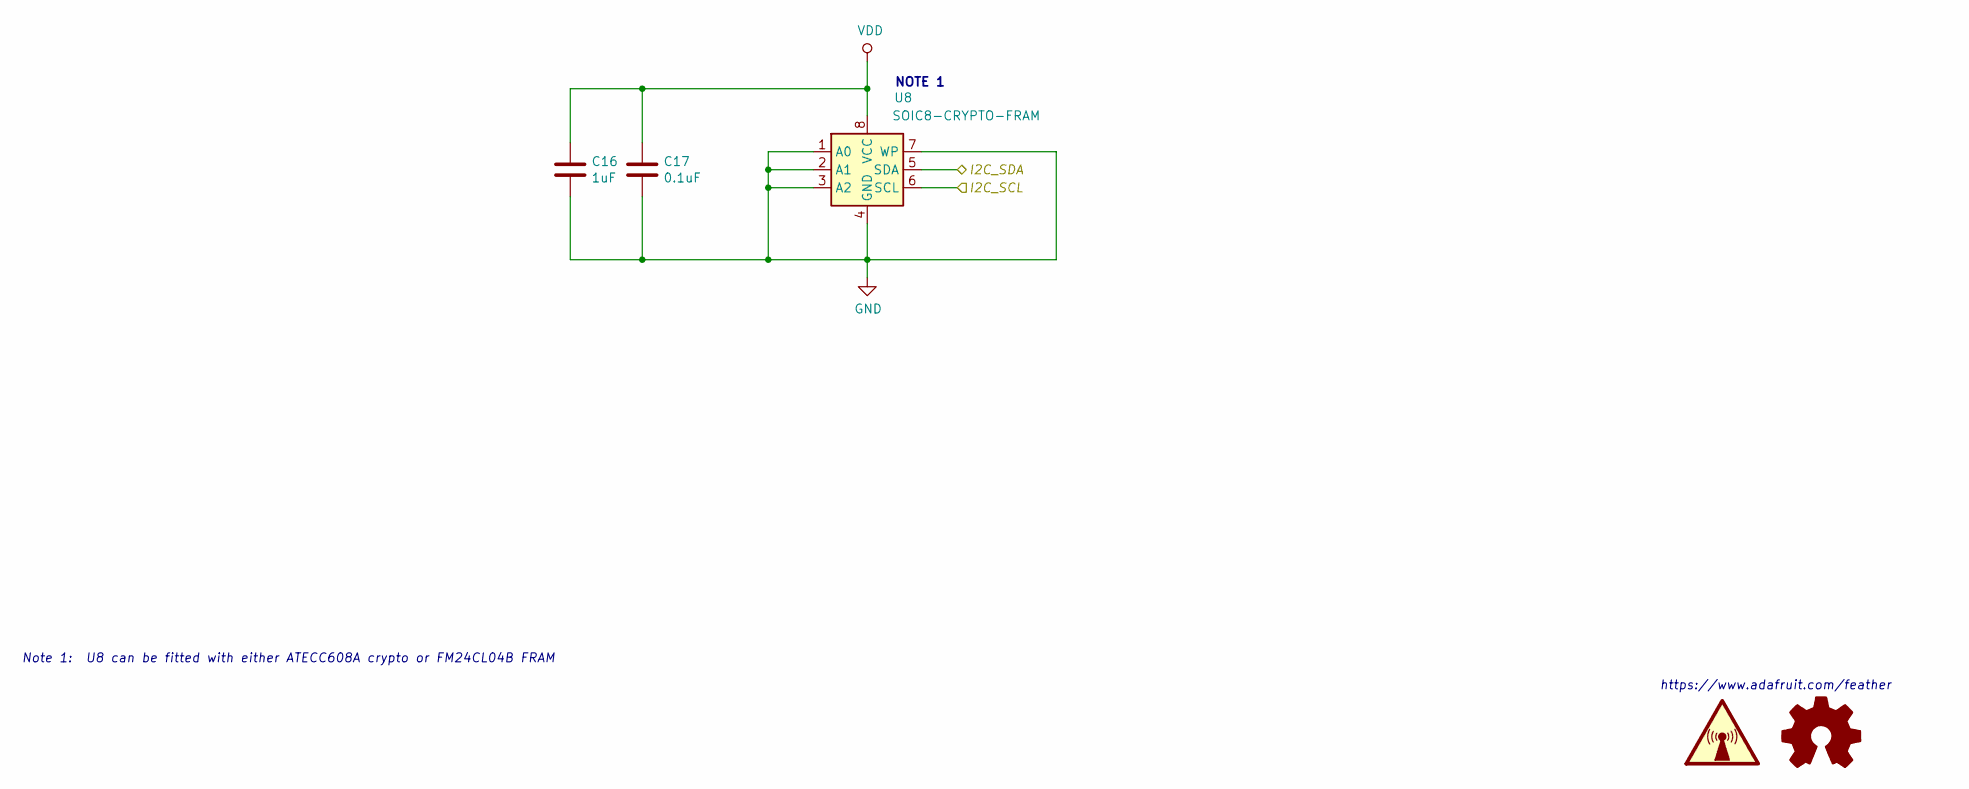
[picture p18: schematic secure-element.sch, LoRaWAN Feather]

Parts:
C16: 1uF; C_0402_1005Metric; LCSC C52923
C17: 0.1uF; C_0402_1005Metric; LCSC C1525
U8: SOIC8-CRYPTO-FRAM; SOIC-8_3.9x4.9mm_P1.27mm

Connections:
/PB6: U8.6 (SCL); also elsewhere on the board
/PB7: U8.5 (SDA); also elsewhere on the board
GND: C16.2, C17.2, U8.1 (A0), U8.2 (A1), U8.3 (A2), U8.4 (GND), U8.7 (WP); also elsewhere on the board
VDD: C16.1, C17.1, U8.8 (VCC); also elsewhere on the board

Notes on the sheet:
https://www.adafruit.com/feather
NOTE 1
Note 1: U8 can be fitted with either ATECC608A crypto or FM24CL04B FRAM

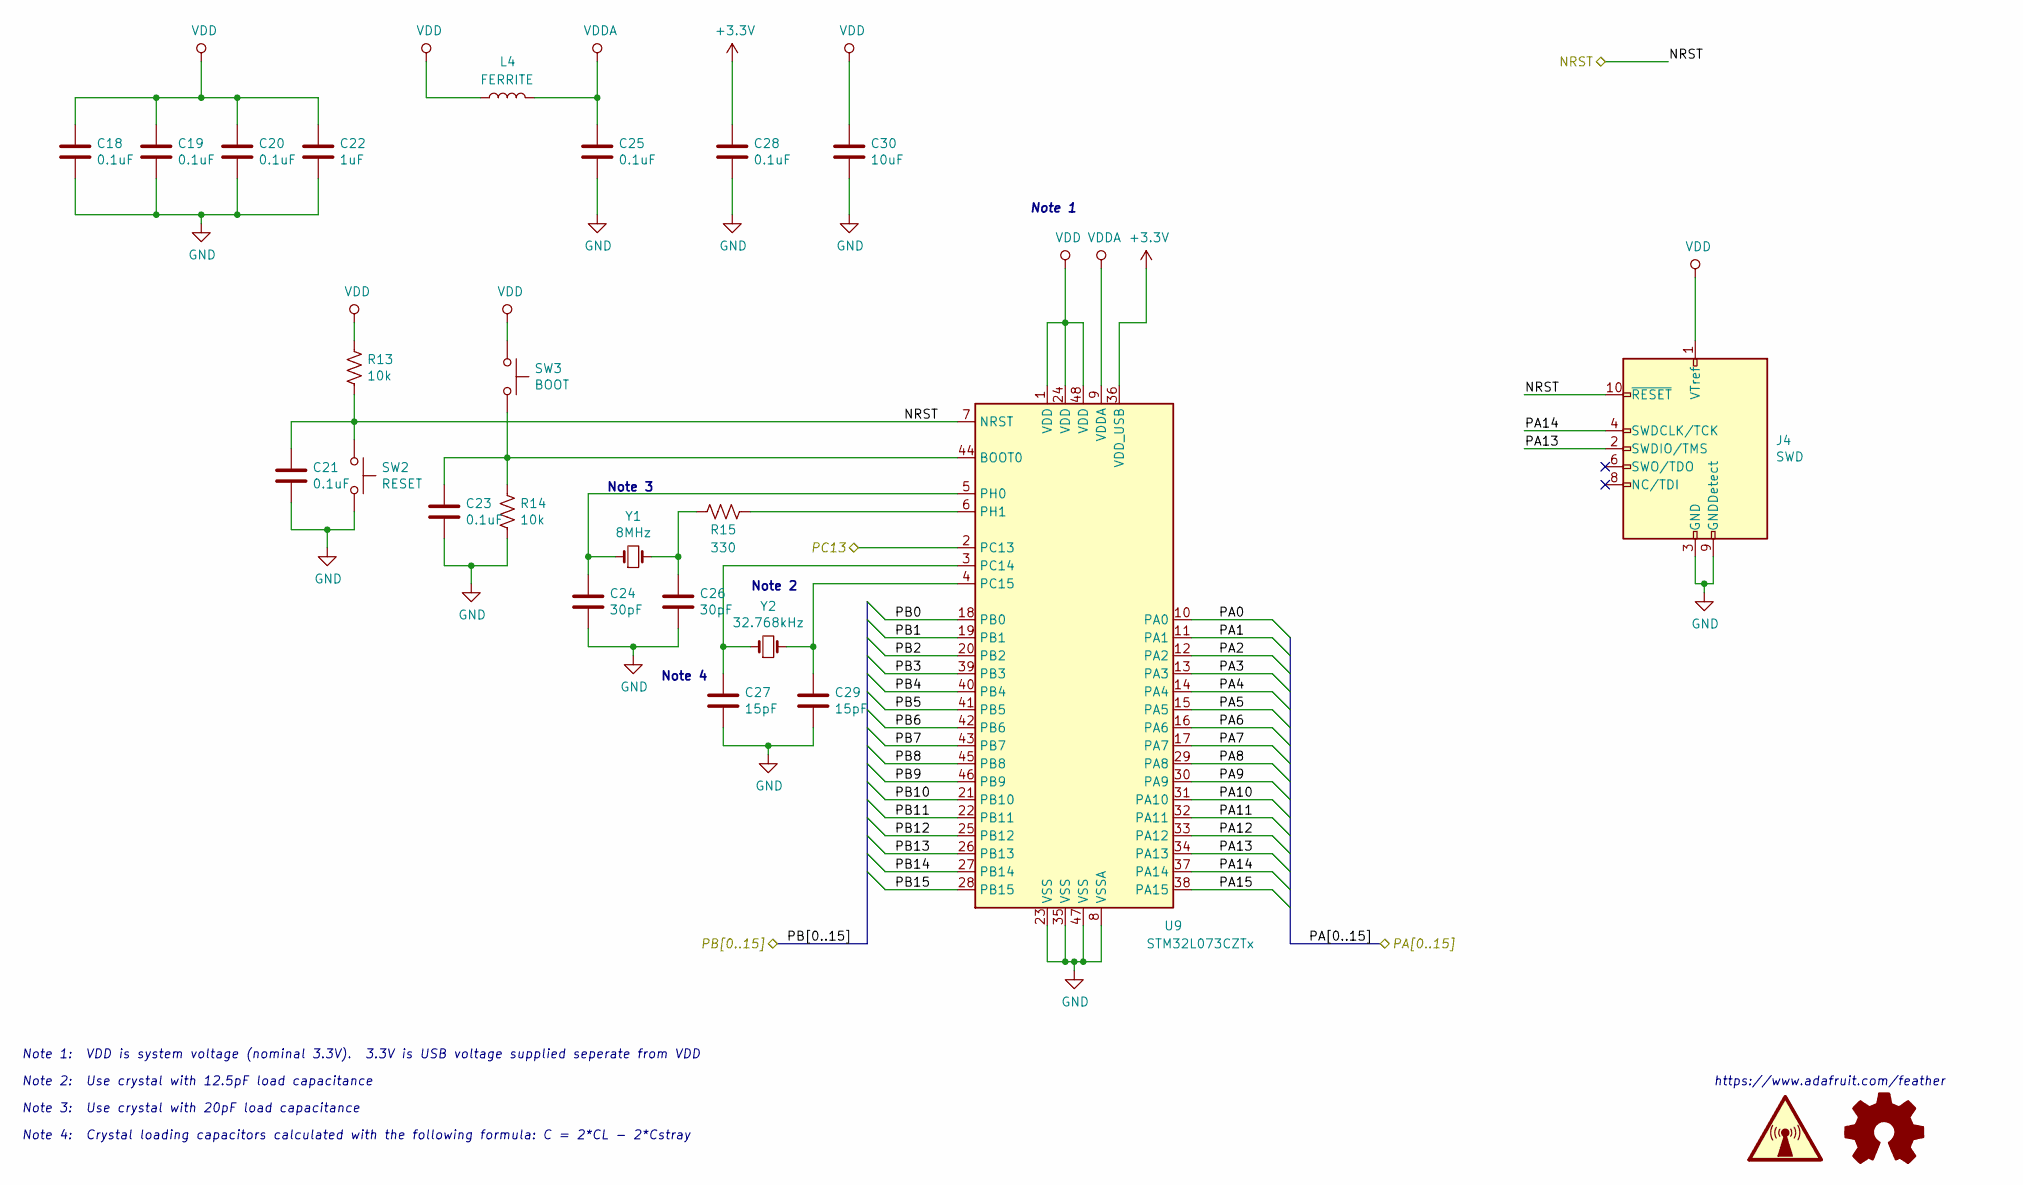
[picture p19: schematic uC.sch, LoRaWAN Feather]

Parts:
C18, C19, C20, C21, C23, C25, C28: 0.1uF; C_0402_1005Metric; LCSC C1525
C22: 1uF; C_0402_1005Metric; LCSC C52923
C24, C26: 30pF; C_0402_1005Metric; LCSC C1570
C27, C29: 15pF; C_0402_1005Metric; LCSC C1548
C30: 10uF; C_0805_2012Metric; LCSC C15850
J4: SWD; PinHeader_2x05_P1.27mm_Vertical_SMD; LCSC DNP
L4: FERRITE; L_0805_2012Metric; LCSC C1015
R13, R14: 10k; R_0402_1005Metric; LCSC C25744
R15: 330; R_0402_1005Metric; LCSC C25104
SW2: RESET; TS_1187A; LCSC C318884
SW3: BOOT; TS_1187A; LCSC C318884
U9: STM32L073CZTx; LQFP-48_7x7mm_P0.5mm; LCSC DNP
Y1: 8MHz; Crystal_SMD_Abracon_ABM3-2Pin_5.0x3.2mm; LCSC C115962
Y2: 32.768kHz; Crystal_SMD_3215-2Pin_3.2x1.5mm; LCSC C32346

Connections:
+3V3: C28.1, U9.36 (VDD_USB); also elsewhere on the board
/IO/PA1: U9.11 (PA1); also elsewhere on the board
/IO/PA2: U9.12 (PA2); also elsewhere on the board
/IO/PA3: U9.13 (PA3); also elsewhere on the board
/IO/PA4: U9.14 (PA4); also elsewhere on the board
/IO/PA7: U9.17 (PA7); also elsewhere on the board
/IO/PB0: U9.18 (PB0); also elsewhere on the board
/IO/PB1: U9.19 (PB1); also elsewhere on the board
/IO/PB2: U9.20 (PB2); also elsewhere on the board
/IO/PB8: U9.45 (PB8); also elsewhere on the board
/IO/PB9: U9.46 (PB9); also elsewhere on the board
/IO/PB10: U9.21 (PB10); also elsewhere on the board
/IO/PB11: U9.22 (PB11); also elsewhere on the board
/IO/PB13: U9.26 (PB13); also elsewhere on the board
/IO/PB14: U9.27 (PB14); also elsewhere on the board
/IO/PB15: U9.28 (PB15); also elsewhere on the board
/NRST: C21.1, J4.10 (~RESET~), R13.2, SW2.1, U9.7 (NRST); also elsewhere on the board
/PA0: U9.10 (PA0); also elsewhere on the board
/PA5: U9.15 (PA5); also elsewhere on the board
/PA6: U9.16 (PA6); also elsewhere on the board
/PA8: U9.29 (PA8); also elsewhere on the board
/PA9: U9.30 (PA9); also elsewhere on the board
/PA10: U9.31 (PA10); also elsewhere on the board
/PA15: U9.38 (PA15); also elsewhere on the board
/PB3: U9.39 (PB3); also elsewhere on the board
/PB4: U9.40 (PB4); also elsewhere on the board
/PB5: U9.41 (PB5); also elsewhere on the board
/PB6: U9.42 (PB6); also elsewhere on the board
/PB7: U9.43 (PB7); also elsewhere on the board
/PC13: U9.2 (PC13); also elsewhere on the board
/uC/PA13: J4.2 (SWDIO/TMS), U9.34 (PA13)
/uC/PA14: J4.4 (SWDCLK/TCK), U9.37 (PA14)
D+: U9.33 (PA12); also elsewhere on the board
D-: U9.32 (PA11); also elsewhere on the board
GND: C18.2, C19.2, C20.2, C21.2, C22.2, C23.2, C24.2, C25.2, C26.2, C27.2, C28.2, C29.2, C30.2, J4.3 (GND), J4.5 (GND), J4.9 (GNDDetect), R14.2, SW2.2, U9.8 (VSSA), U9.23 (VSS), U9.35 (VSS), U9.47 (VSS); also elsewhere on the board
unnamed: C23.1, R14.1, SW3.2, U9.44 (BOOT0)
unnamed: C24.1, U9.5 (PH0), Y1.1
unnamed: C26.1, R15.2, Y1.2
unnamed: C27.1, U9.3 (PC14), Y2.1
unnamed: C29.1, U9.4 (PC15), Y2.2
unnamed: R15.1, U9.6 (PH1)
VDD: C18.1, C19.1, C20.1, C22.1, C30.1, J4.1 (VTref), L4.2, R13.1, SW3.1, U9.1 (VDD), U9.24 (VDD), U9.48 (VDD); also elsewhere on the board
VDDA: C25.1, L4.1, U9.9 (VDDA)

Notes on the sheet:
Note 1
Note 1: VDD is system voltage (nominal 3.3V). 3.3V is USB voltage supplied seperate from VDD
Note 2
Note 3
Note 2: Use crystal with 12.5pF load capacitance
Note 3: Use crystal with 20pF load capacitance
Note 4: Crystal loading capacitors calculated with the following formula: C = 2*CL - 2*Cstray
Note 4
https://www.adafruit.com/feather

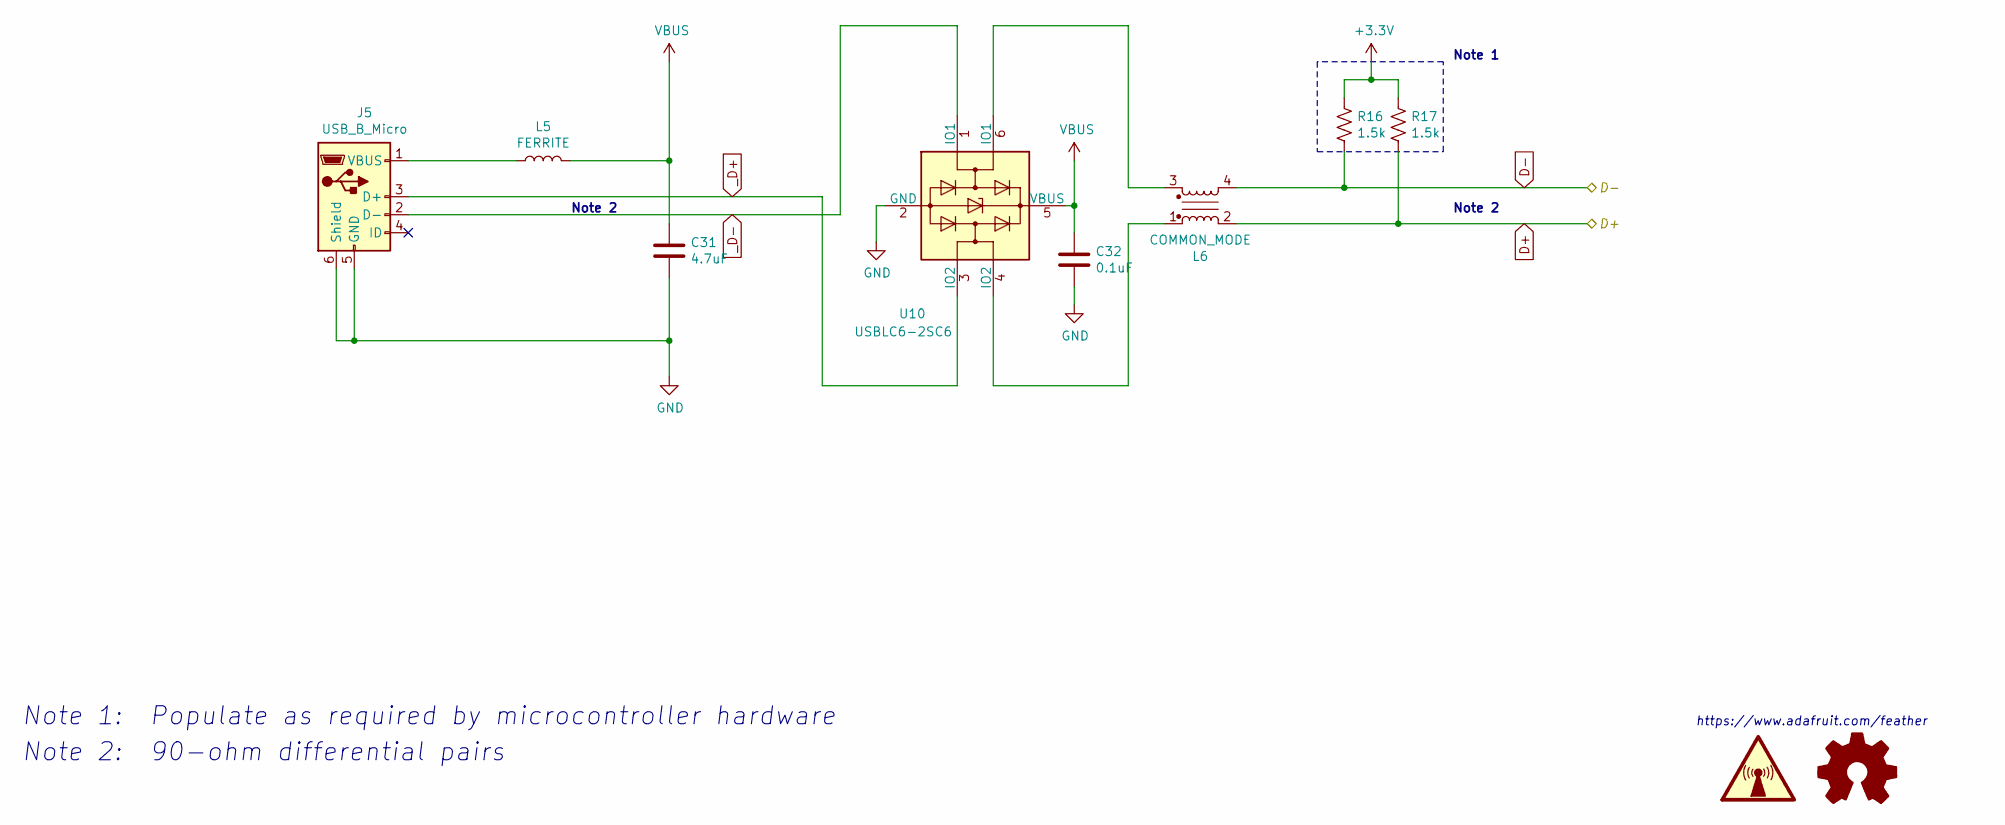
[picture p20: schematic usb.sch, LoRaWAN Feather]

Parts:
C31: 4.7uF; C_0805_2012Metric; LCSC C1779
C32: 0.1uF; C_0402_1005Metric; LCSC C1525
J5: USB_B_Micro; USB_Micro-B_Amphenol_10103594-0001LF_Horizontal; LCSC C428495
L5: FERRITE; L_0805_2012Metric; LCSC C1015
L6: COMMON_MODE; COMMON_MODE_FILTER_0805; LCSC C86163
R16, R17: 1.5k; R_0402_1005Metric; LCSC C25867
U10: USBLC6-2SC6; TSOT-23-6; LCSC C7519

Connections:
+3V3: R16.1, R17.1; also elsewhere on the board
D+: L6.2, R17.2; also elsewhere on the board
D-: L6.4, R16.2; also elsewhere on the board
GND: C31.2, C32.2, J5.5 (GND), J5.6 (Shield), U10.2 (GND); also elsewhere on the board
unnamed: J5.1 (VBUS), L5.1
unnamed: L6.1, U10.4 (IO2)
unnamed: L6.3, U10.6 (IO1)
VBUS: C31.1, C32.1, L5.2, U10.5 (VBUS); also elsewhere on the board
_D+: J5.3 (D+), U10.3 (IO2)
_D-: J5.2 (D-), U10.1 (IO1)

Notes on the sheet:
Note 1
Note 1: Populate as required by microcontroller hardware
Note 2
Note 2: 90-ohm differential pairs
https://www.adafruit.com/feather

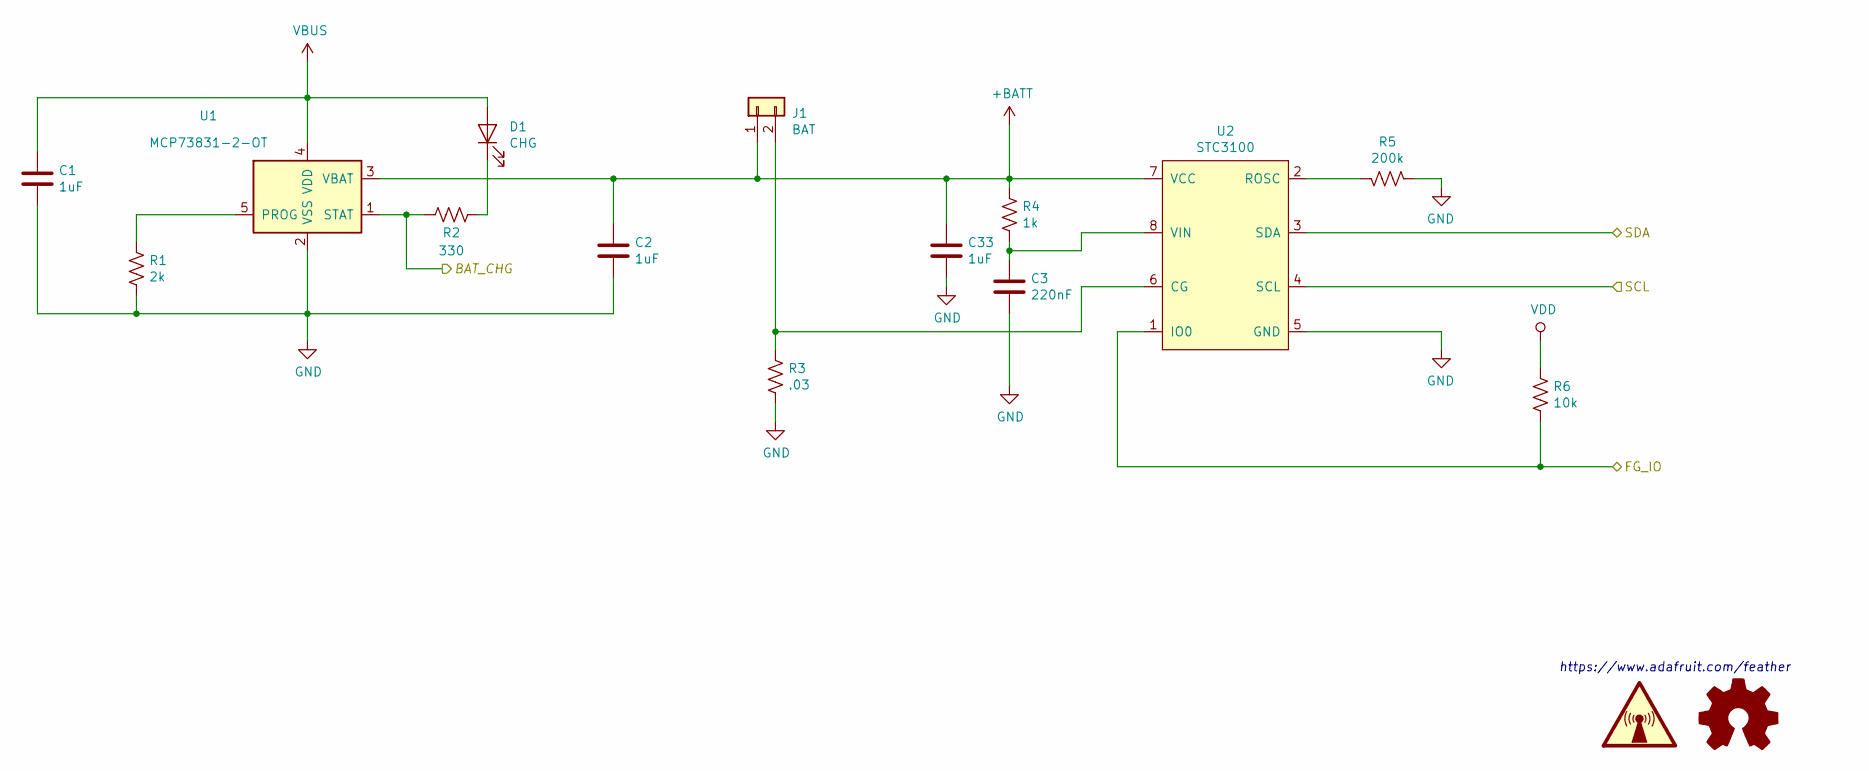
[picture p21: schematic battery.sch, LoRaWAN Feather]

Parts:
C1, C2, C33: 1uF; C_0402_1005Metric; LCSC C52923
C3: 220nF; C_0402_1005Metric; LCSC C16772
D1: CHG; LED_0603_1608Metric; LCSC C72038
J1: BAT; JST_PH_S2B-PH-SM4-TB_1x02-1MP_P2.00mm_Horizontal; Digikey 455-1749-1-ND
R1: 2k; R_0402_1005Metric; LCSC C4109
R2: 330; R_0402_1005Metric; LCSC C25104
R3: .03; R_0805_2012Metric; LCSC C247605
R4: 1k; R_0402_1005Metric; LCSC C11702
R5: 200k; R_0603_1608Metric; LCSC C61953
R6: 10k; R_0402_1005Metric; LCSC C25744
U1: MCP73831-2-OT; TSOT-23-5; LCSC C424093
U2: STC3100; MSOP-8_3x3mm_P0.65mm; Digikey 497-10526-1-ND

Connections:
+BATT: C2.1, C33.1, J1.1, R4.1, U1.3 (VBAT), U2.7 (VCC); also elsewhere on the board
/PA10: R6.2, U2.1 (IO0); also elsewhere on the board
/PA15: R2.2, U1.1 (STAT); also elsewhere on the board
/PB6: U2.4 (SCL); also elsewhere on the board
/PB7: U2.3 (SDA); also elsewhere on the board
GND: C1.2, C2.2, C3.2, C33.2, R1.2, R3.2, R5.2, U1.2 (VSS), U2.5 (GND); also elsewhere on the board
unnamed: C3.1, R4.2, U2.8 (VIN)
unnamed: D1.1 (K), R2.1
unnamed: J1.2, R3.1, U2.6 (CG)
unnamed: R1.1, U1.5 (PROG)
unnamed: R5.1, U2.2 (ROSC)
VBUS: C1.1, D1.2 (A), U1.4 (VDD); also elsewhere on the board
VDD: R6.1; also elsewhere on the board

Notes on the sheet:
https://www.adafruit.com/feather

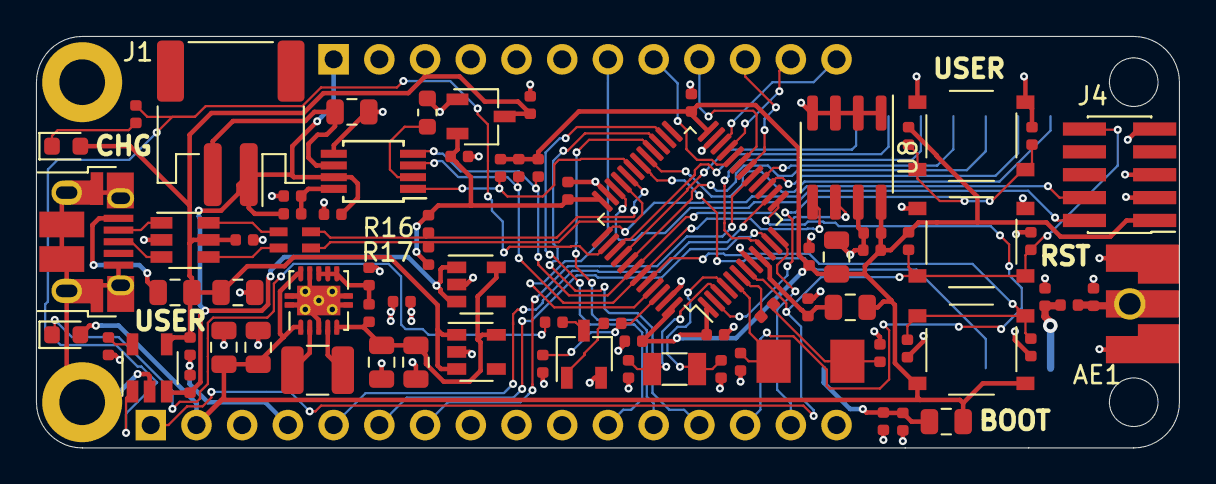
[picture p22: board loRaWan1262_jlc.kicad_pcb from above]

Board: 2 copper layers, 63.5 x 22.9 mm, 86 parts (1 on the bottom side), 66 nets.

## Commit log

2019-11-18 Inital commit
    [battery.sch, io.sch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]
2019-11-18 Add README draft, add 3d image
    [loRaWan1262_jlc.kicad_pcb]
2019-11-19 Add digikey pn's to schematic, update BOM
    [battery.sch, io.sch, loRaWan1262_jlc.csv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]
2019-12-21 PCB REV B0 * Fix STC3100 grounding * Make R16,R17 DNP by default * Bump Bot Silk to REVB0
    [loRaWan1262_jlc-B_Cu.gbr, loRaWan1262_jlc-B_Mask.gbr, loRaWan1262_jlc-B_Paste.gbr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]
2020-01-02 PCB REV C0 * Make U8 footprint capable of crypto and fram device * Minor updates to schematic * Minor updates to doc prints * Update bot silk to REV C0
    [battery.sch, io.sch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]
2020-01-02 Add datasheets for crypto and fram devices
